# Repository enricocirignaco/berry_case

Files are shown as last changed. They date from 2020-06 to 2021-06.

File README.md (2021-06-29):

<!--
*** Thanks for checking out this README Template. If you have a suggestion that would
*** make this better, please fork the berry_case and create a pull request or simply open
*** an issue with the tag "enhancement".
*** Thanks again! Now go create something AMAZING! :D
***
***
***
*** To avoid retyping too much info. Do a search and replace for the following:
*** enricocirignaco(github_username), berry_case(repo), e.cirignaco@gmail.com(email)
-->

<!-- PROJECT LOGO -->
<br />
<p align="center">
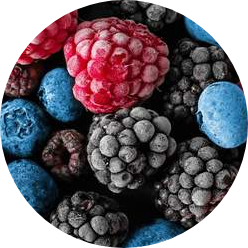
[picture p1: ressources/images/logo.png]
    
  </a>

  <h2 align="center">berry_case</h2>

  <p align="center">
    The open source Raspberry Pi case without compromises made by the community for the communnity
    <br />
    <br />
    <a href="https://github.com/enricocirignaco/berry_case/issues">Report Bug</a>
    ·
    <a href="https://github.com/enricocirignaco/berry_case/issues">Request Feature</a>
  </p>
</p>

<!-- TABLE OF CONTENTS -->
## Table of Contents

* [About the Project](#about-the-project)
  * [Starting Situation](#starting-situation)
  * [Aim](#aim)
  * [Product Requirements](#product-reqirements)
  * [Current Status](#current-status-(15.01.2021))
* [Hardware](#hardware)
  * [Schematics](#schematics)
    * [Main](#main)
    * [Power Supply](#power-supply)
* [Sofware](#software)
  * [Prerequisites](#prerequisites)
  * [Installation](#installation)
  * [Usage](#usage)
* [Mechannic](#mechanic)
* [Sources](#sources)
* [Contributing](#contributing)
* [License](#license)
* [Contact](#contact)

<!-- ABOUT THE PROJECT -->
# About The Project
An affordable and open source case for the Raspberry Pi 4 to help the users became more productive and portable then ever.

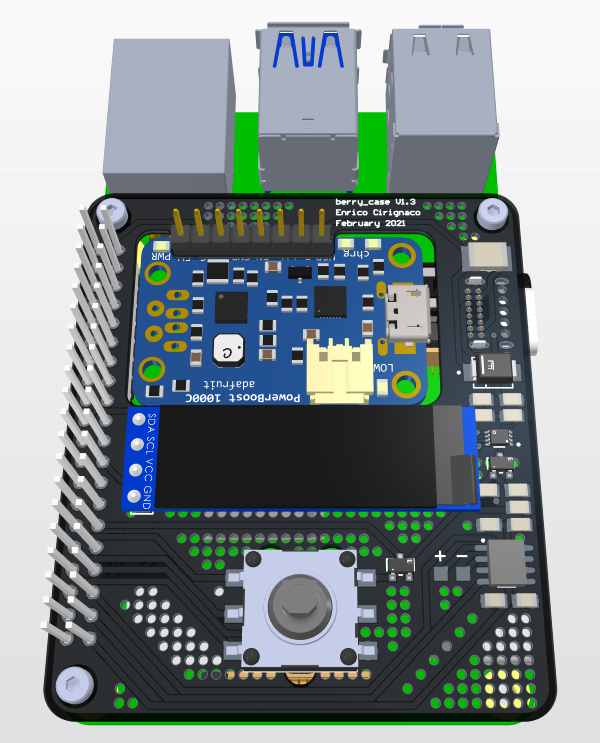
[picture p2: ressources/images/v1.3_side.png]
top_view


## Starting Situation

Surfing on the net I discovered some very cool case solutions for the RPi4. I almost ordered one of those products (Argon One). But then I realized that when the RPi4 was powered by a Power Bank(almost always in my case)(5V@2.1A) the CPU had some serious throttling problems. So overclocking with this power supply was out of discussion. I searched for an alternative battery powered power supply(5.2V@3A). Without success.
At the same time I discovered some interesting "Half-solutions":
* [Argon One](https://www.argon40.com/argon-one-raspberry-pi-4-case.html) (very nice design, power button, cooling system)
* [Acrylic Raspberry Pi set-top box kit](https://wiki.52pi.com/index.php/Acrylic_Raspberry_Pi_set-top_box_kit_SKU:_ZP-0098) (all IOs on the back, full dual HDMI)
* [Raspberry Pi RGB Cooling HAT](https://www.yahboom.net/study/RGB_Cooling_HAT) (OLED dipslay with IP address, CPU temp, etc)
* [Adafruit PowerBoost 1000 Charger](https://www.adafruit.com/product/2465) (UPS solution with Li-Ion cell, power supply)

So I decided to take inspiration from all this product and make my own solution! :)

## Aim
Develop and Build an affordable, open source, smart and good looking case for the Raspberry Pi 4.
Make good documentation and a building guide available to everyone so that anyone can build ther own case at home.
Find someone on github to collaborate with.

## Product Reqirements
* Size: max double the footprint of the RPi4. Max height not defined.
* Battery: min 2 hours of battery life.
* Cooling System: capable of cooling Overclocked RPi4.
* Power Button: capable of Soft and Hard Shutdown.
* PSU: UPS, BMS and 5.2V@min 2A output supply.
* Accessible GPIOs

## Current Status (15.01.2021)
Version 1.2 of the PCB is done. Software still in alpha phase. At the moment I'm focused on the Enclosure. I'm testing different 3D printed cases for the RPi4.

# Hardware
The PCB is developed with [Altium Designer](https://altium.com).
## Schematics
### Main
<a href="https://github.com/enricocirignaco/berry_case/blob/master/ressources/schematics/main.pdf">
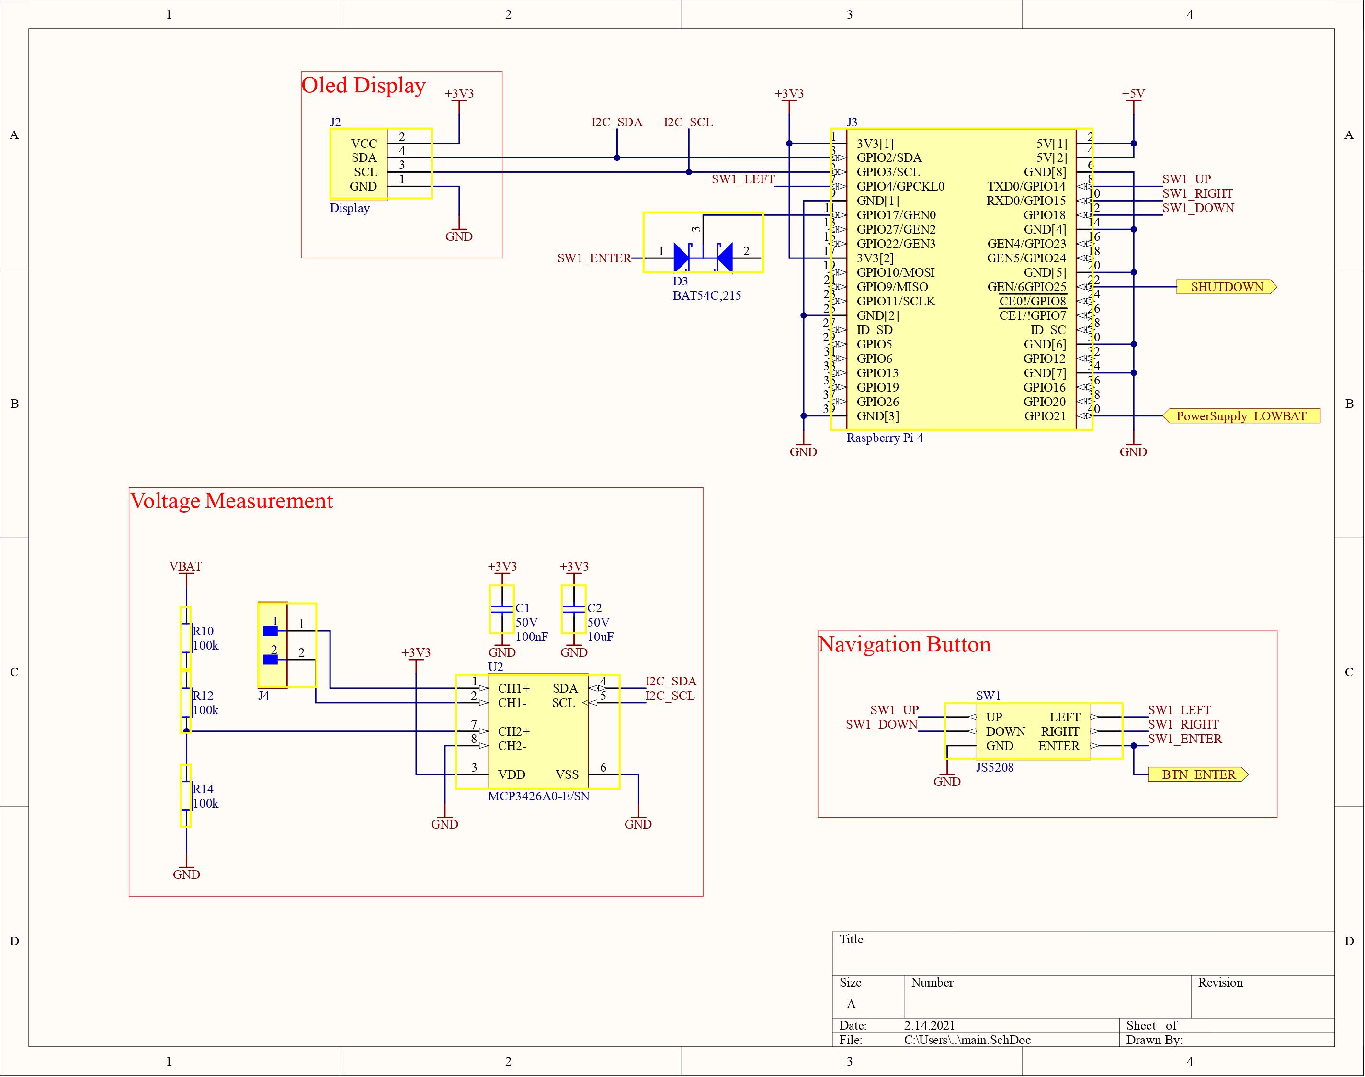
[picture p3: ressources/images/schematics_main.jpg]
  
</a>

### Power Supply
<a href="https://github.com/enricocirignaco/berry_case/blob/master/ressources/schematics/power_supply.pdf">
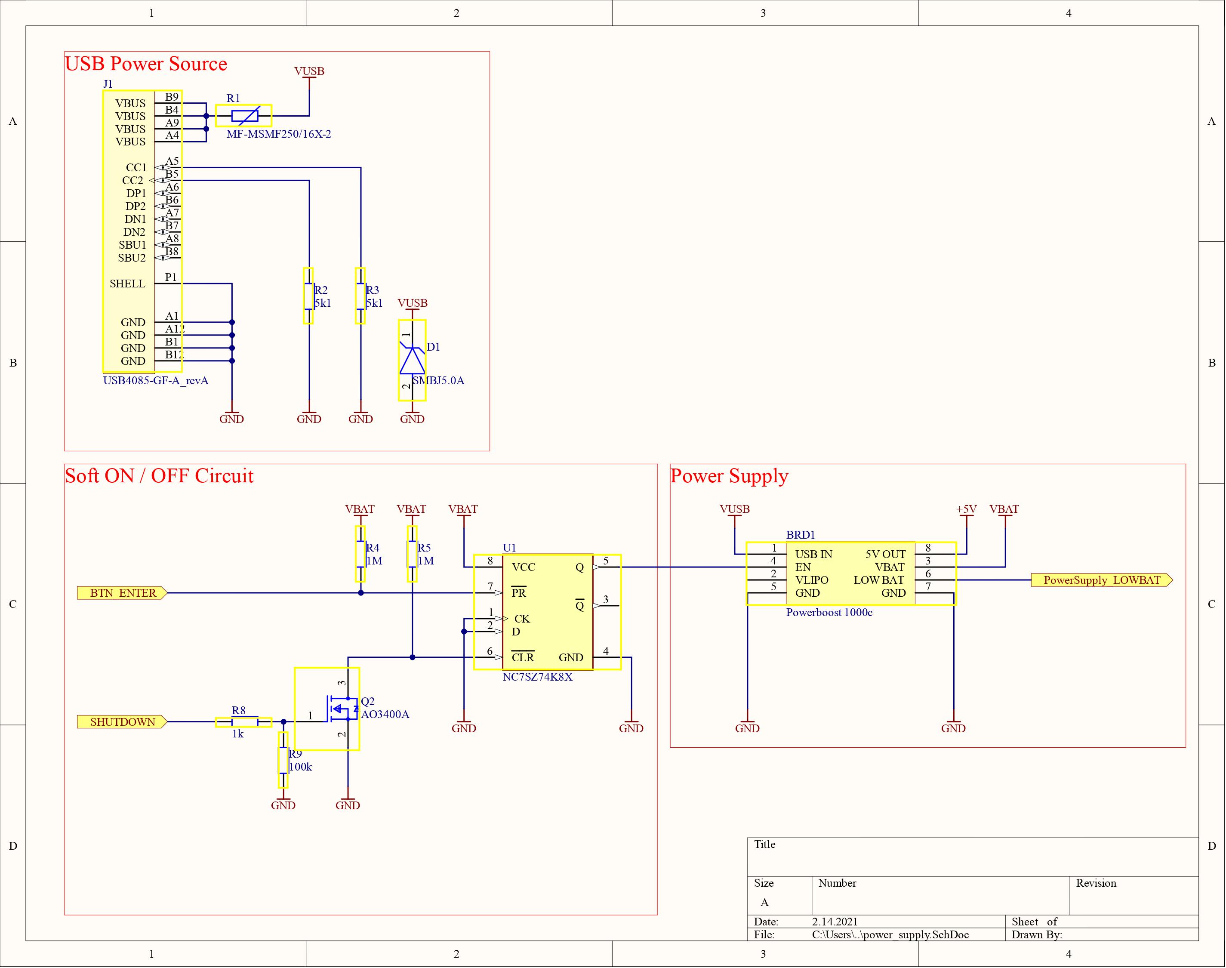
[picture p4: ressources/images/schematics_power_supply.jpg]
  
</a>

# Software
## Prerequisites
## Installation
## Usage
# Mechanic
The 3D Models are developed with [Autodesk Fuson 360](https://www.autodesk.com/products/fusion-360/overview)

# Sources
[datasheet oled display](https://www.mcielectronics.cl/website_MCI/static/documents/0.91inch_OLED_Module_User_Manual_EN.pdf)

[auto power off](http://crsengineering.altervista.org/eng/pi/pi_GPIO_poweroff_eng.html)

[networking tool](https://www.raspberryconnect.com/projects/65-raspberrypi-hotspot-accesspoints/183-raspberry-pi-automatic-hotspot-and-static-hotspot-installer)

# Contributing

I'm looking for someone that want to collaborate in this project. **Especially someone tha is good at 3D drawing.** I would like to get in touch with you if you are interested. :)

Contributions are what make the open source community such an amazing place to be learn, inspire, and create. Any contributions you make are greatly appreciated.

1. Fork the Project
2. Create your Feature Branch (`git checkout -b feature/AmazingFeature`)
3. Commit your Changes (`git commit -m 'Add some AmazingFeature'`)
4. Push to the Branch (`git push origin feature/AmazingFeature`)
5. Open a Pull Request

# License

# Contact

Enrico Cirignaco - e.cirignaco@gmail.com

Project Link: [https://github.com/enricocirignaco/berry_case](https://github.com/enricocirignaco/berry_case)

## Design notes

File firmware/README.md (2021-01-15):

# setup
## Install python libraries
* Run **install_oled.sh** script in the shell
* When installation script is done **raspi-config** window will open. 
    * Navigate to **Interface Options** and enter.
    * Navigate to **I2C** and confirm with yes.
    * Exit raspi-config
* Add user to GPIO, i2c and video group:
    * sudo adduser \<username> GPIO
    * sudo adduser \<username> i2c
    * sudo adduser \<username> video
* Reboot machine by typing **sudo reboot**

### add main.py script to programms to run at startup

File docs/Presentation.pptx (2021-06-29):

## Willkommen

## 37.000.000

Bis heute verkaufte Raspberry Pi

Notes: Allein in 2020 wurden 7 Milionen raspberry verkauft.
Ich selber besitze verschiedene modelle.
Ich entwickle fast täglich auf einem Raspberry

## Ziel dieses Projektes: Ein Zusatzmodul entwickeln um den Raspberry portabler zu machen

## Kritische Features

- Kommunikation mit dem Benutzer

Internetzugang

Akkubetrieb

Unterbruchsfreie Stromversorgung

## Zusäzliche Features

- Aktive und passive Kühlung des Prozessors

Benutzeroberfläche

Gehäuse für Raspberry & Zusaztmodul

ON/OFF Knopf

## Das Endprodukt:

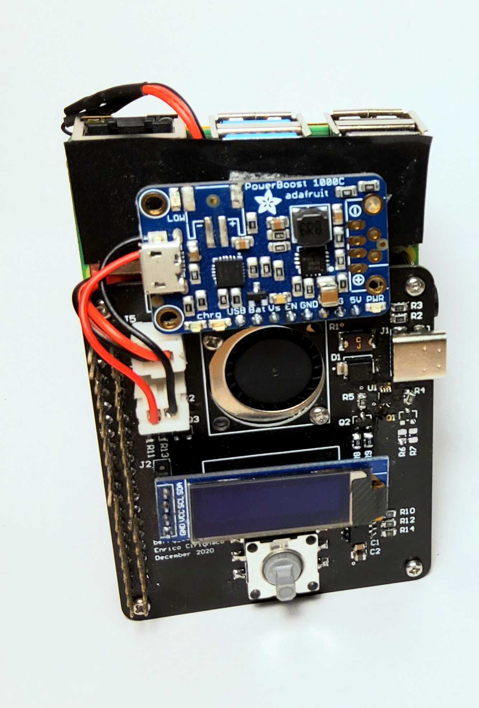
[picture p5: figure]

berrycase

## Netzwerk

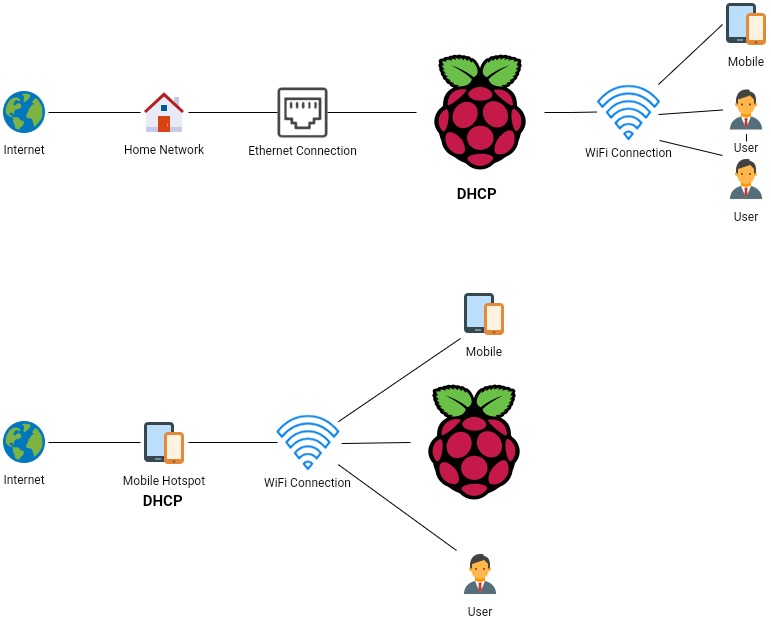
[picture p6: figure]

Access Point

Eigene Wi-Fi Netzwerk

## Speisung

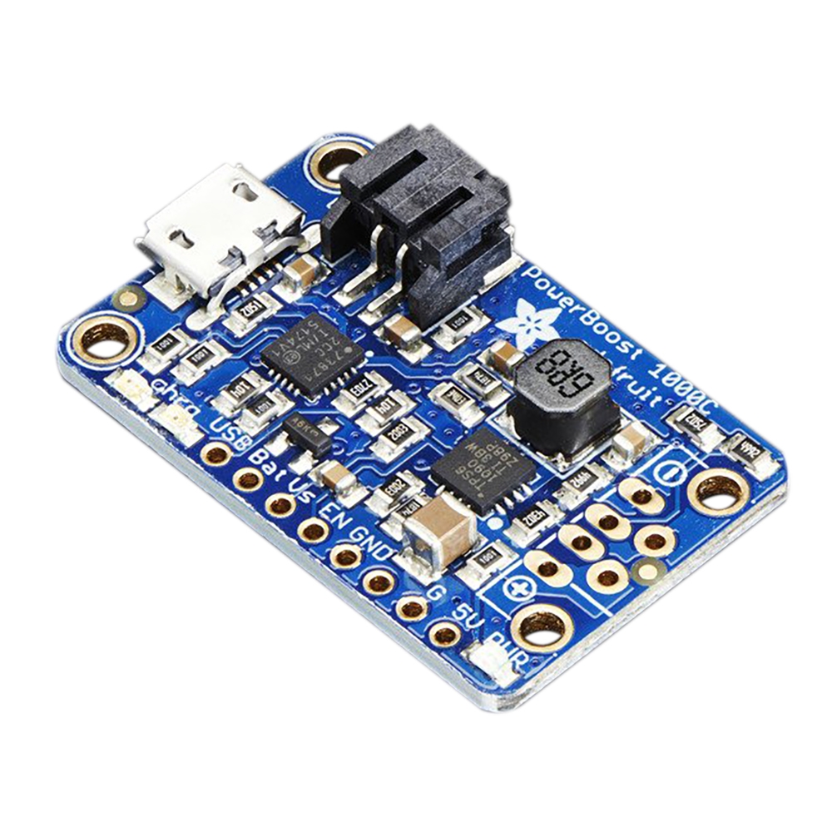
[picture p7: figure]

- MCP73871: Stand-Alone System Load Sharing and Li-Ion / Li-Polymer Battery Charge Management Controller
- TPS61090: Synchronous (96% Efficient) Boost Converter

## Benutzeroberfläche

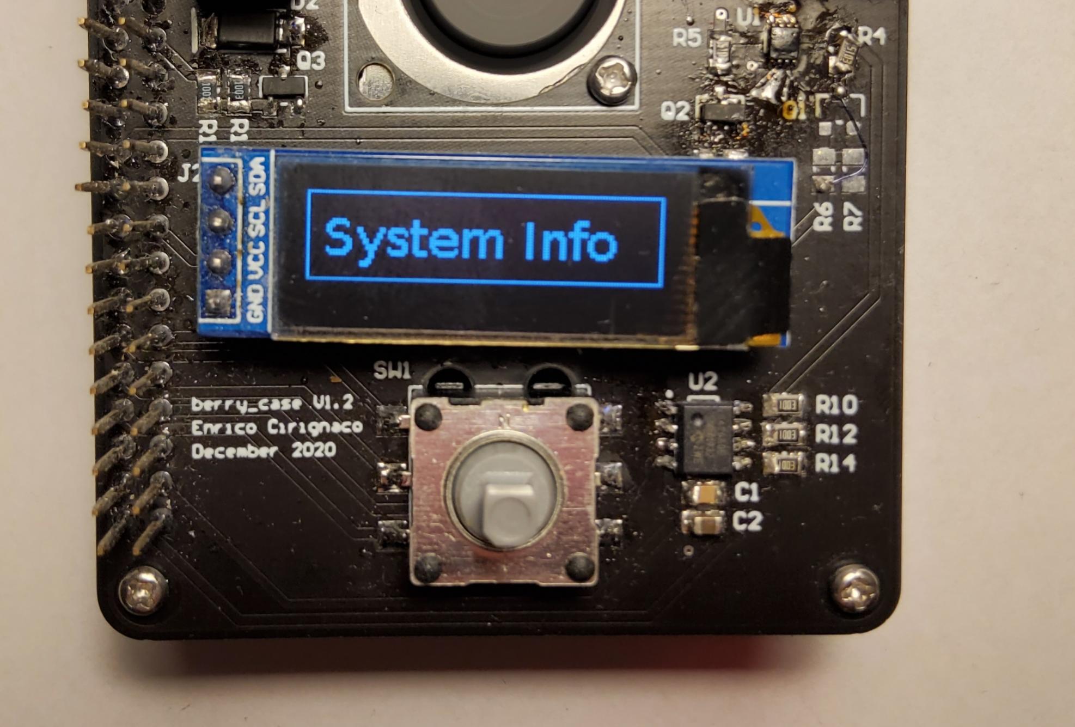
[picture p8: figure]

- 0.96 Zoll OLED Display
- Intuitiver Navigationstaster

## Kühlungsystem

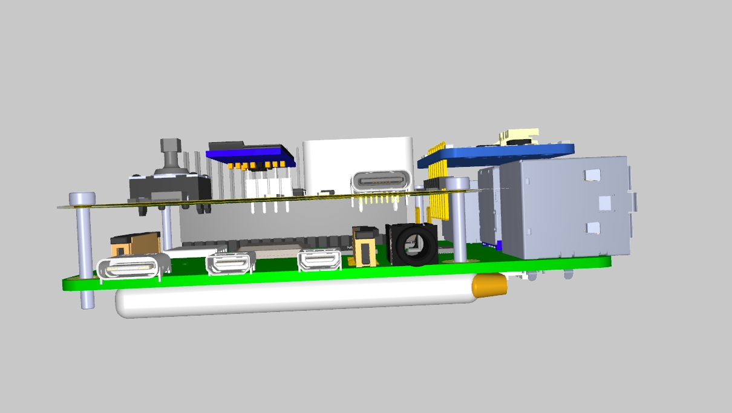
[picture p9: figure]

## Wie weiter?

- Komplettes Open-Source Projekt auf Github: enricocirignaco/berry_case
- Ein Gehäuse muss entwickelt werden
- Weitere Iterationen sind geplant
- Mithelfer gesucht

## Fragen oder Verbesserungsvorschläge?

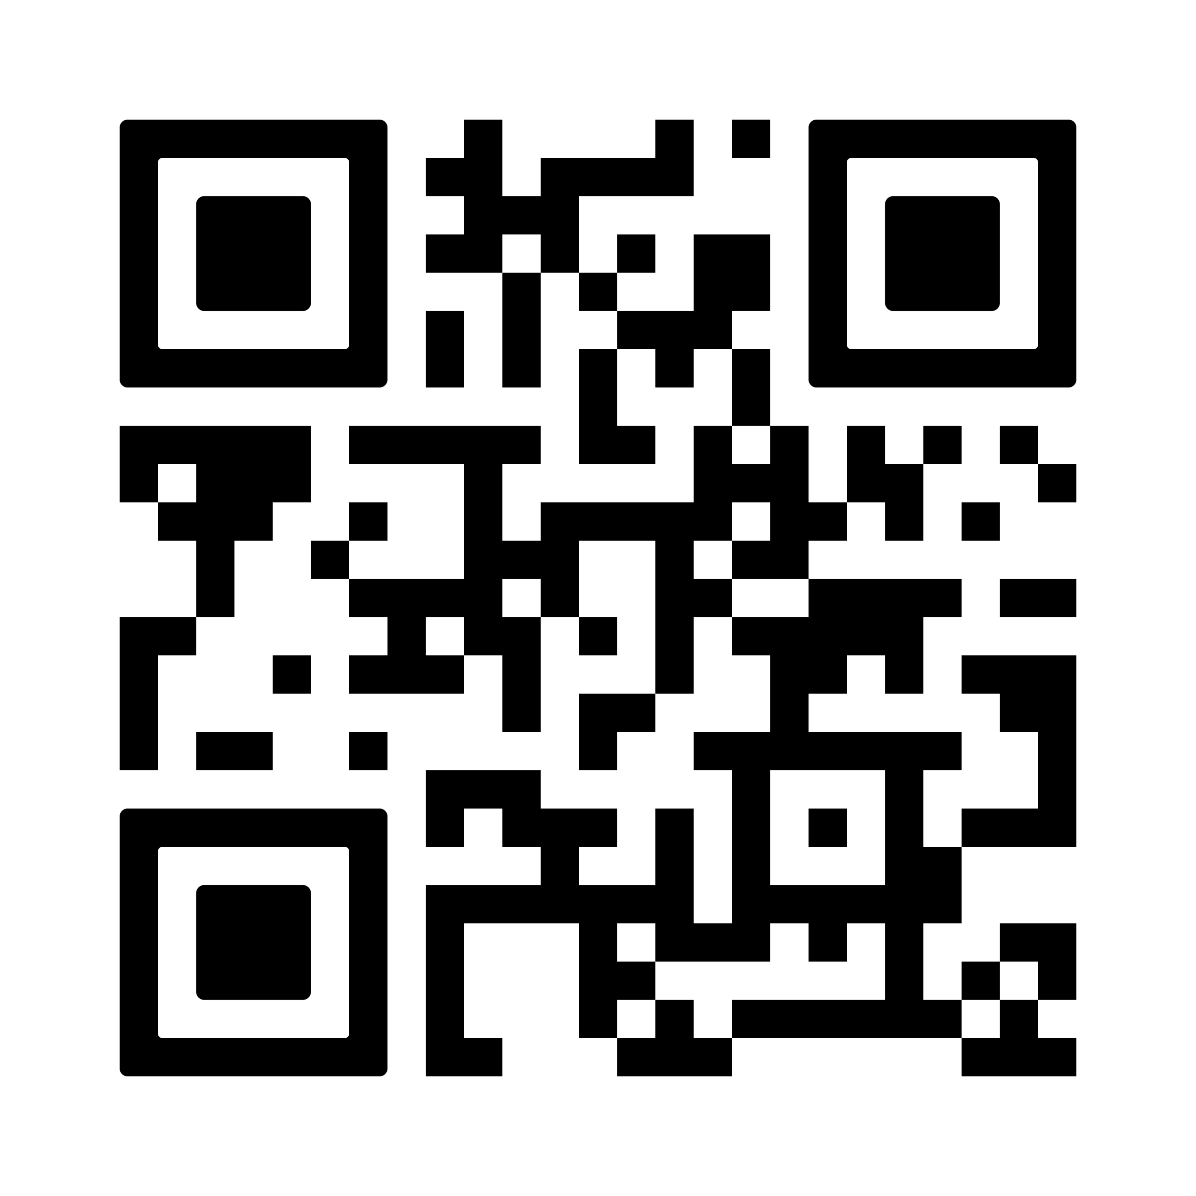
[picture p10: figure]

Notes: Falls jemand an das Projekt interesse hat kann diese QR code zu den github repository scannen.

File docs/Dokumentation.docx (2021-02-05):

Berrycase

# Berufsübergreifendes Projektarbeit

Eine Dokumentation über die Entwicklung ein multifunktionales Gehäuse für den Einplatinencomputer Raspberry Pi 4B.

Autor: Enrico Cirignaco
Fachvorgesetzte: Matthias Burri
Auftraggeber: Matthias Burri 05.02.21

# Abstract

Die im nachfolgenden Dokument beschriebene Arbeit wurde im Rahmen einer Berufsübergreifenden Projektarbeit (BüP) durchgeführt:

Die Aufgabe lautete, ein Gerät zu entwickeln das ermöglicht, unterwegs mit dem Raspberry zu arbeiten und die allgemeine Produktivität der Benutzer zu steigern. Daher muss eine ansteckbarer Leiterplatte und ein Gehäuse entwickelt werden. Im Gehäuse muss einen Akku integriert werden, so dass das Gerät auch ohne Netzspeisung benutzt werden kann.

Als Vorarbeit zu dieser Aufgabe wurde eine kleine Marktanalyse gemacht, um zu wissen ob ähnliche Lösungen auf dem Markt schon vorhanden sind. Dazu wurde auch die technische Machbarkeit untersucht.

Das Gehäuse ist mit einem OLED Display und ein Navigationsknopf ausgestattet. Damit können Einstellungen gemacht werden und Systeminformationen eingeblendet werden. Um den Rechner kühl zu behalten wurde im Gerät ein 20mm Lüfter eingebaut. Die Geschwindigkeit des Lüfters kann mit einem automatischen oder einem manuellen Modus angesteuert werden. Die Kerneigenschaft vom berrycase ist die UPS Funktion (aus dem Englischen Unterbrechungsfreie Stromversorgung). Dies ermöglich vom Akkubetrieb auf Netzbetrieb (und umgekehrt) zu wechseln, ohne das System herunterfahren zu müssen.

Am Ende der Arbeit wurden alle grundlegenden Ziele erreicht und es konnte sogar begonnen werden, am optionalen Ziel zu arbeiten. Dieses wurde aber nicht abgeschlossen. Verbesserungen, die noch implementiert werden könnten, wären das 3D Gehäuse fertig zu entwickeln und auszudrucken. Zudem könnte ein grösserer Akku eingebaut werden. Das Kühlungssystem könnte auch so erweitert werden, dass die CPU/GPU übertaktet werden kann.

Inhaltsverzeichnis

# Abbildungsverzeichnis

# Abkürzungsverzeichnis

OLED Organic Light Emitting Diode

UPS Uninterruptible Power Supply

CPU Central Processing Unit

GPU Graphics Processing Unit

UX User Experience

IP Internet Protocol

GPIO General-purpose input/output

BüP Berufsübergreifendes Projekt

BMS Battery management system

AP Access Point

I2C Inter-Integrated Circuit

PCB Printed Circuit Board

PWM Pulse-Width Modulation

RS-Flip-Flop Reset Set Flip Flop

D-Flip-Flop Data Flip Flop

MOSFET Metal Oxide Semiconductor Field Effect Transistor

kV Kilovolts

BVDSS Drain-Source Breakdown Voltage

VDS Drain-Source Voltage

SoC System on a chip

PIR Passive Infrared Sensor

TVS Transient-voltage-suppression diode

PTC Positive Temperature Coefficient
ADC Analog-Digital-Converter
I/O Inputs/Outputs
LED Light Emitting Diode
uC Mikrocontroller
GND Ground
V Volt
A Ampere
IC Integrated Circuit

# 1 Einleitung

Im Rahmen einer Vorbereitung für die zukünftige Individuelle Projektarbeit soll dieses Projekt durchgeführt werden.

## 1.1 Aufgabenstellung

Den Raspberry Pi unterwegs zu benutzen ist sehr umständlich. Eine Powerbank ist nötig und ein Netzwerk muss aufgesetzt werden. Um die UX (Nutzererfahrung) zu steigern, muss ein Gehäuse für den Einplatinencomputer entwickelt und gebaut werden.

Das Gehäuse muss klein gehalten werden. Eine UPS Funktion muss implementiert werden. Man muss Minimum zwei Stunden im Akkubetrieb arbeiten können. Das Gehäuse muss mit einem Kühlungssystem für die CPU und einem kleinen Display, um die IP-Adresse anzuzeigen ausgestattet werden. Die GPIOs von Raspberry müssen zugänglich bleiben.

## 1.2 Vorgehen

Während der Dauer der BüP soll das Konzept erarbeitet werden, die Elektronik entwickelt und gefertigt werden.

Zusätzlich muss die Software geschrieben werden. Folgende Arbeiten gehören zur BüP:

• Grobplanung

• Vorstudie

• Konzept erarbeiten

• Hardware Entwicklung

• Firmware / Software Entwicklung

• Testing / Bugfixing

• Dokumentation

Das Projekt wird mit der „Agilen Arbeitsmethodik“ geleitet. Dementsprechend wird in der Startphase nur eine Grobplanung gemacht und die Meilensteine werden festgesetzt. Ein SCRUM Board und das Project Management Tool „Trello“ werden eingesetzt.

Das Projekt wird mit GIT verwaltet und auf Github dokumentiert. Alle Projektunterlagen sind Open-Source. Das Arbeitsjournal wird elektronisch geführt.

## 1.3 Zielsetzung

Das Projekt wurde in zwei Zielbereiche unterteilt. In einen grundlegenden und in einen optionalen Zielbereich.

### Grundfunktionen

- Batteriebetrieb (Minimum zwei Stunden Autonomie)
- Aktives Kühlungssystem
- Einschaltknopf
- Ausschaltknopf (mit soft Shutdown)
- Unterbrechungsfreie Stromversorgung (UPS)
- Batteriemanagementsystem (BMS)
- Die GPIOs vom Raspberry müssen zugänglich bleiben
- Das Gehäuse darf maximal doppelt so gross wie der Raspberry sein
- Display, um Informationen anzuzeigen
- Stromversorgung über USB Type-C

### Optional

Die optionalen Ziele sollen erst realisiert werden, sobald die Grundfunktionen alle einwandfrei funktionieren. Optional soll mithilfe eines CAD Tools ein passendes Kunststoff Gehäuse gezeichnet und mit einem 3D Drucker ausgedruckt werden.

# 2 Hardware

## 2.1 Konzept

In diesem Abschnitt sollen die einzelnen Schaltungsteile analysiert und evaluiert werden. Hierbei ist darauf zu achten, dass einige Teile der Schaltung von vorhergegangenen und Open Source Projekten übernommen wurden und daher nicht überall neue Evaluationen durchgeführt wurden.

### Mikrokontroller

Die Funktion der Mikrokontroller übernimmt in diesem Fall der Raspberry Pi selber. Der Mikrokontroller dient in dieser Anwendung zur Ansteuerung der einzelnen Hardwarekomponenten und als Router für das aufgesetzte Netzwerk.

#### 2.1.1.1 Vorgaben

Der Kontroller muss folgende Punkte erfüllen:

- Auf dem Kontroller muss ein Wi-Fi AP (Access Point) aufgesetzt werden können
- PWM zu Ansteuerung der Lüfter
- I2C zu Ansteuerung des Displays und der ADC
- Es werden insgesamt 7 I/Os (Inputs/Outputs) benötigt, um die Hardwareteile anzusteuern.

### OLED Display

Um nutzvolle Informationen anzuzeigen wurde entschieden, ein OLED Display einzusetzen. Die Hauptvorteile diese Technologie sind, dass keine Hintergrundbeleuchtung benötigt wird und seine hervorragender Kontrasteigenschaft. Dazu sind diese Displays preisgünstig und stromsparender. Das ausgewählte OLED Display hat eine Bilddiagonale von 0.91 Zoll und eine Auflösung von 128x32 Pixels. Die Anzeige kann mit 3.3v und 5v gespeist werden. Angesteuert wird sie über das I2C Protokoll.

Abbildung 1: OLED Display

### UPS & BMS

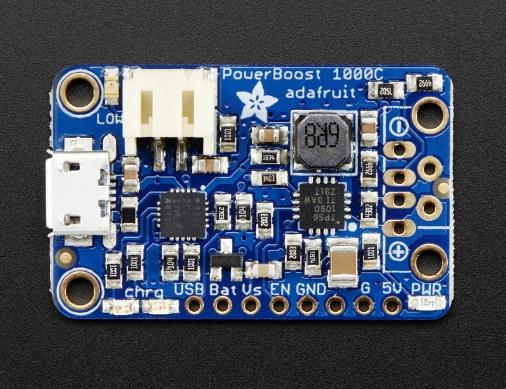
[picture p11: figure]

Auf dem Markt gibt es schon eine Lösung, die genau die in diesem Projekt benötigten Funktionalitäten aufweist. Der PowerBoost 1000c des Herstellers Adafruit. Die Entwicklungsunterlagen dieses Produkts sind frei zugänglich und Open-Source. Es wurde zuerst evaluiert ob es sinnvoll wäre, die Schaltung auf eine eigene Leiterplatte zu integrieren oder das Produkt von Adafruit zu übernehmen. Zwei kritische Bauteile der Schaltung können nur mit speziellen Werkzeugen bestückt werden. Dazu ist der Preisunterschied zwischen den zwei Varianten nicht sehr gross. Es wurde darum entschieden die fertige Leiterplatten von Adafruit einzukaufen und im Projekt zu integrieren.

Abbildung 2: PowerBoost 1000C

### Soft-Power OFF

Der Raspberry muss mithilfe der Benutzeroberfläche ausgeschaltet werden können. Nachdem der Raspberry heruntergefahren wird, verbraucht das System weiter Energie. Als Folge wäre die Batterie innerhalb ein paar Stunden komplett leer. Um dieses Problem zu umgehen, muss die Speisung ausgeschaltet werden. Das kann mit der Ansteuerung der «Enable» Pin der PowerBoost 1000c Board realisiert werden.

### Batterie-Spannungsmessung

Die Spannung kann einfach mit einem Spannungsteiler umgewandelt werden und mit einem ADC ausgewertet werden. Da der Raspberry Pi nicht mit einem ADC ausgestattet ist, muss ein Externes evaluiert werden. Für die Kommunikation zwischen ADC und uC soll das Protokoll I2C angewendet werden. Der MCP3426 vom Hersteller Microchip wurde ausgewählt.

Der gewählte AD-Wandler besitzt folgende Eigenschaften:

- 16bit Auflösung
- 2 Differenzeingänge
- Delta-sigma verfahren
- I2C Schnittstelle

## 2.2 Realisierung

In diesem Abschnitt wird auf die Realisierung der Hardware genauer eingegangen und die einzelnen Schaltungsblöcke werden genauer erklärt.

### Blockschaltbild

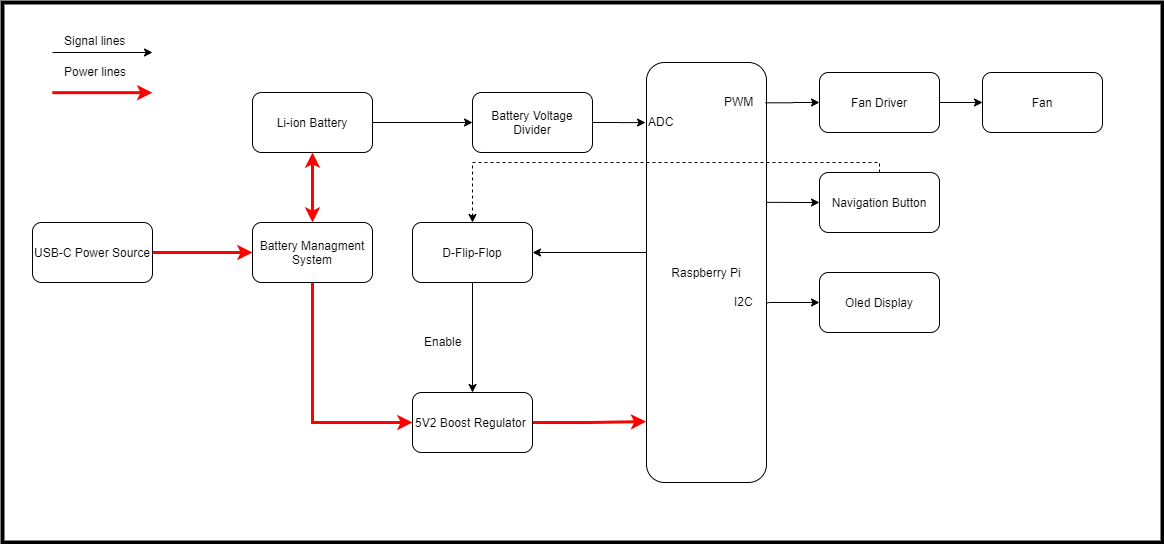
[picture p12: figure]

Abbildung 3: Blockschaltbild

### Mikrokontroller

Der Mikrocontroller ist der Kern der Hardware und steuert alle anderen Baugruppen. Integriert auf dem Board ist auch die 3.3V Speisung.

### Speisung

Das Gerät wird über USB gespeist, somit ist die Speisung schon vorhanden. Was noch implementiert worden ist, ist eine Schutzschaltung, um das Gerät gegen Überspannungen und Überlastungen zu schützen. Die Schaltung wurde von einem vorherigen Projekt übernommen. Die TVS Diode D1 dient als Schutz gegen Überspannungen. Der Widerstand R1 ist eine PTC rücksetzbare Sicherung, die bei einem Strom von 2.5A oder höher ihr interner Widerstand erhöht und konsequent die Schaltung trennt.

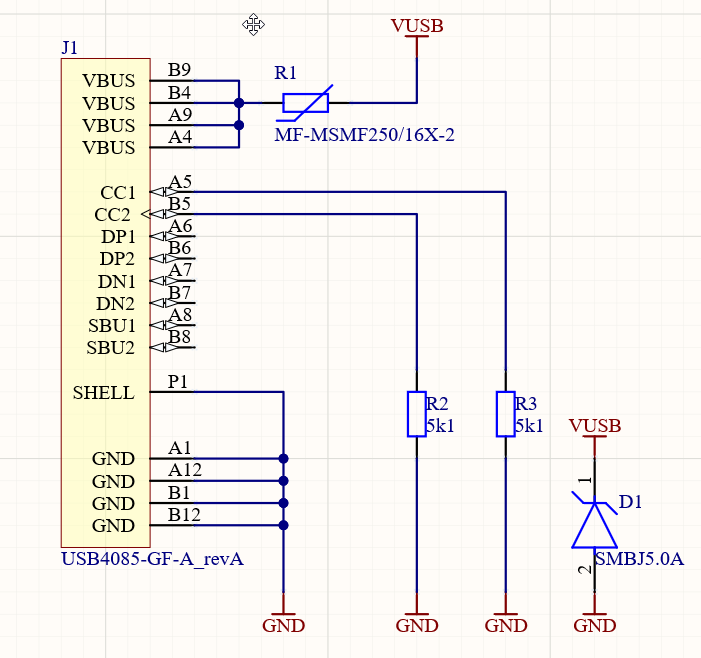
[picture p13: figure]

Abbildung 4: USB Type-C und Schutzschaltung

Wie im Dokument «Introduction to USB Type-C™» von Microchip empfohlen wird, wurden zwei 5k1 Widerstände zwischen Ground und Pin CC1 und CC2 von der USB Buchse bestückt. Diese stellen sicher, dass das Gerät mit genügend Leistung von der USB-Speisung versorgt wird.

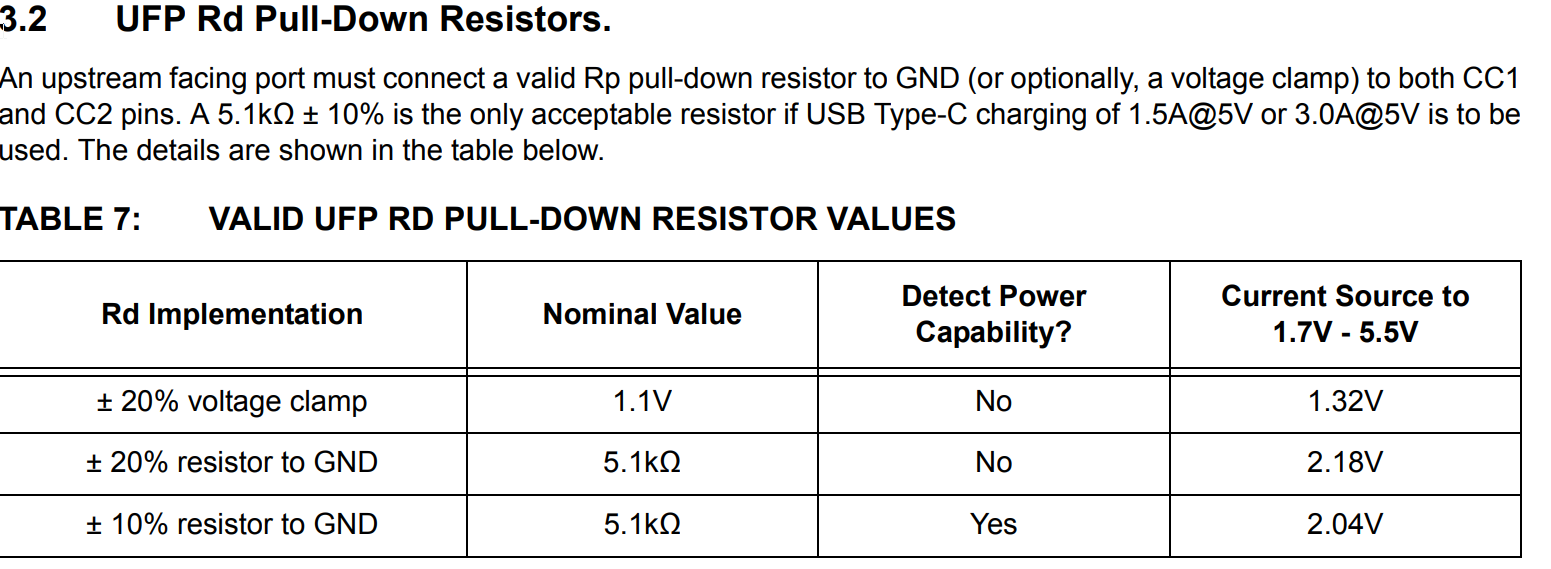
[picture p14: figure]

Abbildung 5: Ausschnitt aus dem PDF «Introduction to USB Type-C™»

Teil der Speisung ist auch das externe Board PowerBoost 1000c. Die externe Speisung, die Batterie und der 5V Ausgang müssen an diese Schaltung angeschlossen werden. Zusätzlich sind eine Leitung für den Enable Pin und eine Leitung für den Batteriezustandmelder mit dem Board verbunden.

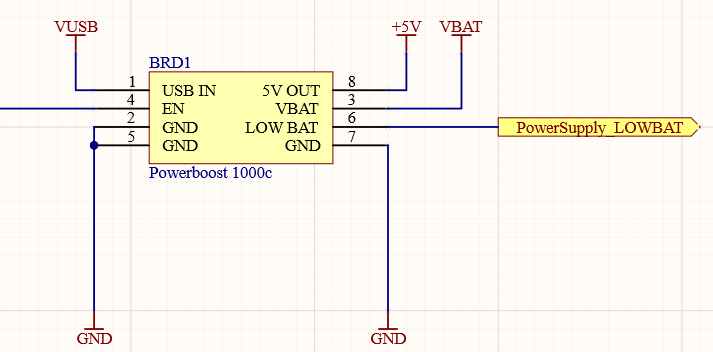
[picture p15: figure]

Abbildung 6: PowerBost 1000c

### Batterie Spannung Messung

Die Messung der Spannung erfolgt über den Spannungsteiler (R10-R12-R14). Da die drei Widerstände genau den gleichen Wert haben (±1%), entspricht die Ausgangspannung einem Drittel der Eingangsspannung. Dieser Pegel wird dann mit dem ADC ausgewertet. Der ADC arbeitet mit einer internen Spannungsreferenz von 2,048V. Die maximale Spannung an den Differenzeingängen darf diesen Wert nicht überschreiten. C1 und C2 schützen den ADC gegen Störungen.

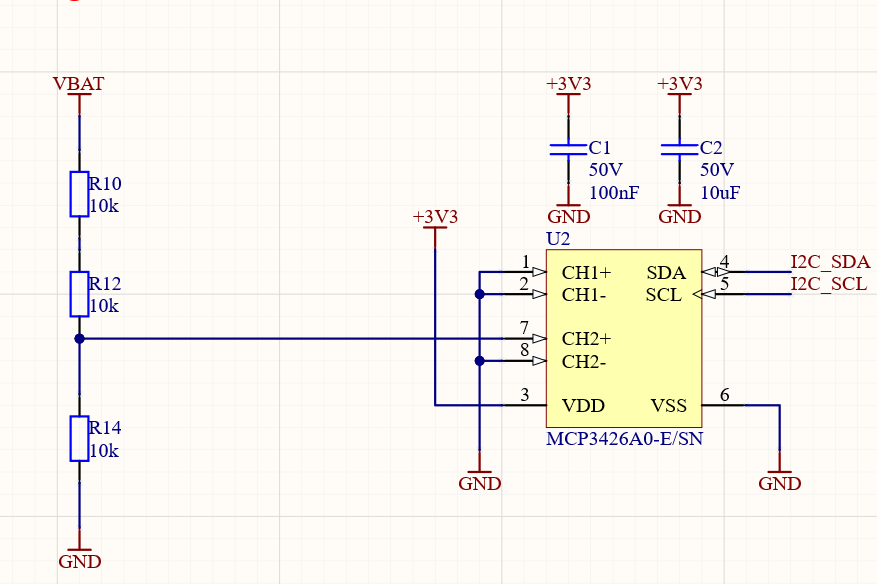
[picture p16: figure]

Abbildung 7: Spannungsmessung

### Soft Power ON/OFF Schaltung

Der Schaltregler auf dem PowerBoost Board kann mit der Ansteuerung der Enable Pin ein- und ausgeschaltet werden. So kann die Speisung den Raspberry Pi komplett trennen.

Abbildung 8: : Ausschnitt aus dem Datenblatt vom TPS61090

Um den Enable Pin immer in einem definierten Zustand ohne externe Handlung zu behalten, wird er mit einem RS-Flip-Flop angesteuert. Dieser Flip-Flop Typ ändert seinen Ausgangszustand nur, wenn eine Flanke auf dem Set oder Reset Pin detektiert wird. Das ausgewählte Flip-Flop ist der NC7SZ74K8X des Herstellers ON Semiconductor. Dieses Model kann entweder als D- oder RS-Flip-Flop verwendet werden. Für diese Anwendung wird ein RS Typ benötigt. Anhand der unterstehenden Wahrheitstabelle kann man sagen, dass wenn eine negative Flanke auf dem Clear Pin ist, wird die Speisung ausgeschaltet und wenn eine negative Flanke auf dem Preset Pin ist, wird die Speisung eingeschaltet.

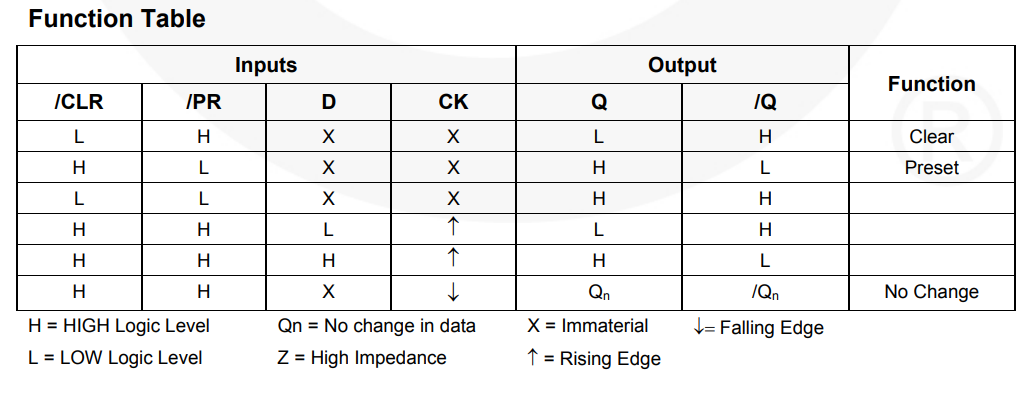
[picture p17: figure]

Abbildung 9: Ausschnitt aus dem Datenblatt vom NC7SZ74K8X

Da der Logikpegel des Raspberry niedriger als die Spannung der Batterie ist, wird ein Pegelwandler benötigt. Dieser wurde mit zwei MOSFET (Q1 und Q2) realisiert.

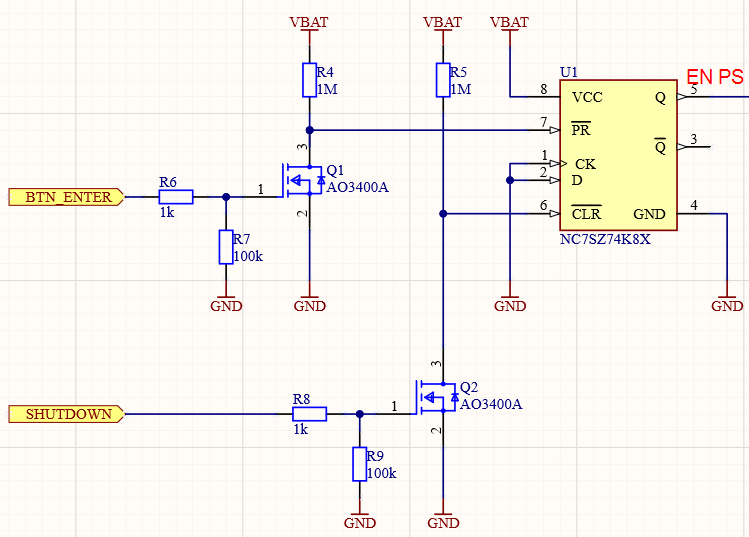
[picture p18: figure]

Abbildung 10: Soft ON/OFF Schaltung

### Lüfter Steuerung

Der Lüfter wird mit einem PWM Signal angesteuert. So kann die Geschwindigkeit des Lüfters fein eingestellt werden. Da ein GPIO vom Raspberry nicht die benötigte Leistung erbringen kann, wird die Leistung mit einem MOSFET angesteuert. Der Motor des Lüfters ist eine induktive Last. Folglich, wenn die Schaltung geöffnet wird und kein elektrischer Strom mehr fliesst, bricht das magnetische Feld in den Wicklungen des Motors zusammen und eine elektrische Spannung wird induziert. Diese Spannung kann bis zu einigen kV (Kilovolts) gross werden. Die MOSFET sind allgemein auf grosse Spannungen sehr empfindlich. Die in diesem Projekt angewendete AO3400A hat eine BVDSS (Drain-Source Breakdown Voltage) von nur 30V. Ohne ein Überspannungsschutz würde der MOSFET nach einigen Schaltvorgängen kaputt gehen. Um dieses Problem zu umgehen wurde die Freilaufdiode D2 eingebaut. Damit wird sichergestellt, dass die VDS Spannung (Drain-Source Voltage) von Q3 nie grösser als 5.7V wird.

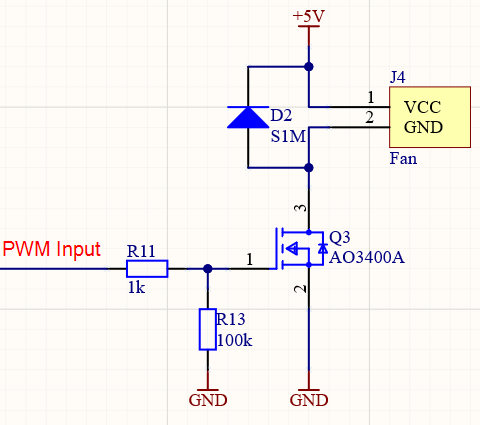
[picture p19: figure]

Abbildung 11: Lüfter Steuerung Schaltung

### Bedienung Komponenten

Die Bedienung des Geräts erfolgt über ein OLED Display und einen 5-fachen Navigationsknopf. Das Display wird über I2C angesteuert und mit 3.3V gespiesen. Die Pull-up Widerstände für die I2C sind auf dem Raspberry schon vorhanden. Der Navigationsbutton ist direkt mit 5 GPIOs der Raspberry Pi verbunden. Pull-up Widerstände werden dann Softwaremässig eingeschaltet. Die Entprellung wird auch Softwaremässig implementiert.

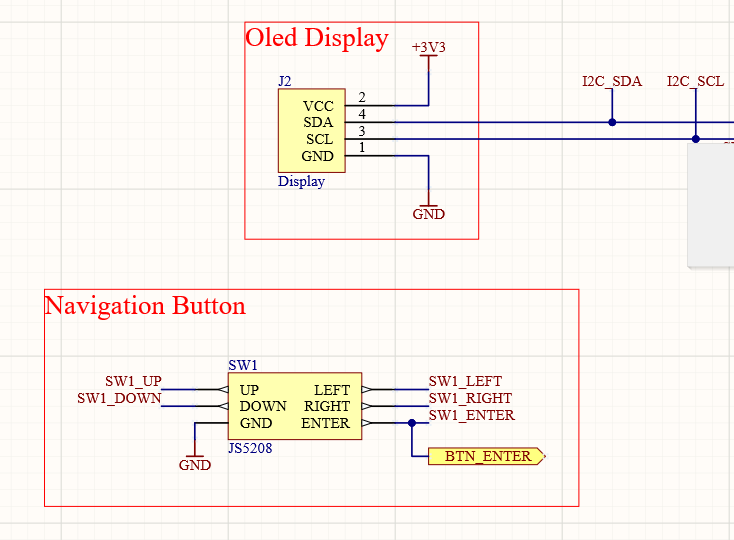
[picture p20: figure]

Abbildung 12: Bedienung Komponenten Schaltung

# 3 Software

In diesem Abschnitt der Dokumentation sollen die einzelnen Teile der Software analysiert und erklärt werden. Die Software besteht aus einem Hauptprogramm und verschiedenen kleineren unabhängigen Skripts.

## 3.1 Hauptprogramm

Die Software für die Steuerung der Hardware wurde in Form von Python Skripts geschrieben. Das Hauptprogramm ist zuständig für die Interaktion mit dem Benutzer.

### Aufbau

Die Software wurde modular strukturiert. Das bedeutet, dass jede Peripherie in ein eigenes Modul aufgeteilt ist und alle Funktionen, welche für die Ansteuerung der jeweiligen Peripherie benötigt werden, darin enthalten sind. Diese Files können im Hauptprogramm als Python Module eingebunden werden. Lediglich alle Variablen und Parameter wurden in den entsprechenden Modulen zusammengefasst.

### Ablauf Flussdiagramm

Der Softwareablauf entspricht grundsätzlich dem Modell eines Flussdiagramms. Dies liegt daran, dass solange keine Taster gedrückt werden, das Programm immer denselben Ablauf durchführt. Erst sobald eine Callback von der GPIOs ausgelöst wird, wird gehandelt. Aus diesem Grund wird die Software mit Hilfe des Flussdiagramms in Abbildung 10 dargestellt.

Wenn das Programm gestartet wird, wird automatisch der erste Eintrag des Hauptmenus auf dem Display dargestellt. Mit den Tasten Hoch und Runter kann man zwischen den verschiedenen Einträgen navigieren. Um in ein Untermenü zu gehen muss der Knopf in der Mitte gedrückt werden. Analog zu Hauptmenü können die Untermenüs mit den Tasten Hoch und Runter gesteuert werden. Um zurück in das Hauptmenü zu gelangen muss die Taste in der Mitte gedrückt werden.

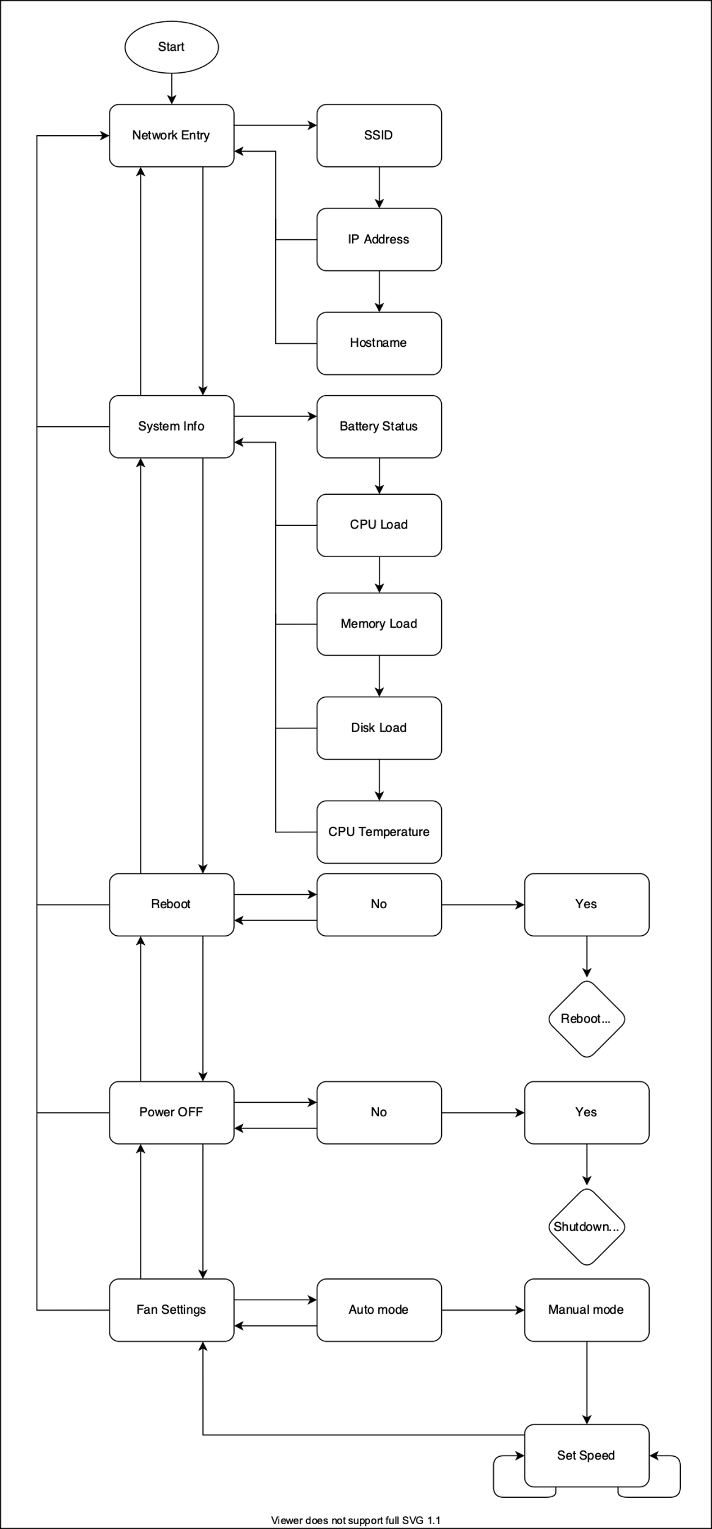
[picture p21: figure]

Abbildung 13: Flussdiagramm Hauptprogramm

### Konfiguration

Damit der Python Script fehlerfrei funktionieren kann, müssen die benötigten Python Libraries installiert werden. Zusätzlich muss die Hardware einmalig konfiguriert werden. Um diese Aufgaben zu erledigen wurde ein Shell Skript geschrieben. Beim Ausführen wird zuerst das Betriebssystem auf den neusten Stand aktualisiert. Danach werden die benötigten Programme, falls nicht vorhanden, installiert. Gleichzeitig wird Python3 als Standard Python Interpreter eingestellt. Danach werden die Python Libraries installiert, um die GPIOs und das Display ansteuern zu können. Schliesslich wird der I2C Bus aktiviert und die I2C Clock vom Standardwert von 100kHz auf 1Mhz eingestellt.

### System Befehle

Um auf Systeminformationen zuzugreifen wurden Bash Befehle benutzt. Bash ist die Standard Linux Shell. Mithilfe einer Funktion des «subprocess» Standardmodul können innerhalb ein Python Script Bash Befehle ausgeführt werden. Das Resultat wird dann in Variablen gespeichert.

#### 3.1.1.1 SSID

iwgetid -r

Mit diesem Befehl kann der Name des Wi-Fi Netzwerks, mit dem das Gerät momentan verbunden ist, ausgeben.

#### 3.1.1.2 IP-Adresse

hostname -I | cut -d' ' -f1

Mit diesem Befehl kann die IP-Adresse ausgegeben werden. Mithilfe des «cut» Befehls wird die Ausgabe formatiert.

#### 3.1.1.3 CPU-Auslastung

top -bn1 | grep load | awk '{printf \"%.2f%%\", $(NF-2)}'

Mit diesem Befehl wird die CPU-Auslastung in Prozent ausgegeben. Mit dem Befehl «awk» wird den Wert mit zwei Nachkommastellen formatiert und danach das Prozentzeichen «%» angehängt.

#### 3.1.1.4 CPU-Temperatur

cat /sys/class/thermal/thermal_zone0/temp | awk '{printf \"%.2f\", $1/1000}'

Mit diesem Befehl wird die CPU-Temperatur in Milligrad Celsius ausgegeben. Mithilfe des «awk» Befehls wird den Wert in Grad Celsius umgerechnet und mit zwei nachkommastellen ausgegeben.

#### 3.1.1.5 RAM-Auslastung

free -m | awk 'NR==2{printf \"%.2f%%\", $3*100/$2 }'

Mit diesem Befehlt werden die frei verfügbare Programspeicher und die gesamten physisch installierten Speicher ausgegeben. Beide Werten in Megabytes. Mit dem «awk» Befehl wird die frei verfügbarer RAM in Prozent ausgerechnet und mit zwei relevanten Nachkommastellen ausgegeben.

#### 3.1.1.6 Flash Speicher Auslastung

df -h | awk \'$NF=="/"{printf "%d/%dGB %s", $3,$2,$5}\'

Mit diesem Befehl werden die gesamten physisch installierten Speicher in Gigabytes und der frei verfügbare Speicher in Gigabytes und in Prozent ausgegeben. Mit dem Befehl «awk» werden die Werte formatiert ausgegeben.

## 3.2 Auto Startup

Das Hauptprogramm muss nach jedem Neustart automatisch gestartet werden. Zudem muss das Skript in Hintergrund laufen. Es hat verschieden Möglichkeiten, diesen Vorgang zu automatisieren. Es wurde entschieden, das Tool Cron einzusetzen.

### Crontab

Aus dem Wikipedia Artikel über Cron:

«Der Cron-Daemon dient der zeitbasierten Ausführung von Prozessen in Unix und unixartigen Betriebssystemen wie Linux, BSD oder macOS, um wiederkehrende Aufgaben – Cronjobs – zu automatisieren.»

Grundsätzlich können Aufgaben in ein sogenannten Crontab File hinzugefügt werden, dazu muss spezifiziert werden, wann die Aufgaben ausgeführt werden müssen (Zeit oder Ereignisse wie z.B. Neustart). Jeder Benutzer hat ein Cron File.

Um dieses File zu öffnen muss folgendes Kommando ausgeführt werden:

crontab -e

In diesem Fall sieht der Eintrag für diese Aufgabe so aus:

@reboot /home/dev/documents/berry_case/firmware/python/autostart.sh

In anderen Worten, nach jedem Neustart führt das Skript «autostart.sh» aus.

### Autostart Skript

Das Skript sieht so aus:

# Project: berry_case

# File: autostart.sh

# Autor: Enrico Cirignaco

# Created: 11.12.2020

# Description: This script need to be added to the crontab of the pi user.

# crontab -e --> @reboot /home/dev/documents/berry_case/firmware/python/autostart.sh

# This script just run the main Python script wit sudo rights in background.

#!/bin/bash

cd /home/dev/documents/berry_case/firmware/python/

sudo -E python3 ./main.py &

Bevor das Hauptprogramm ausgeführt werden kann muss sichergestellt werden, dass man sich im richtigen Directory befindet. Das geschieht mit dem «cd» Kommando. Danach wird das Hauptprogramm mit Python, als Administrator im Hintergrund ausgeführt.

## 3.3 Netzwerk

Das Netzwerk von Raspberry muss so aufgesetzt werden, dass beim Neustart nach einem bekannten Wlan-Netzwerk gesucht wird. Wenn eins gefunden wird, wird eine Verbindung hergestellt. Wenn kein bekanntes Netzwerk gefunden wurde, wird auf dem Raspberry ein Access Point eingerichtet.

Somit kann sich der Benutzer in jeder Situation mit dem Raspberry verbinden.

Auf dem Internet wurde ein Tool gefunden, mit dem das gewünschte Netzwerk eingerichtet werden kann. Dieses Tool wurde netterweise vom Besitzer der Webseite raspberryconnect.com zu Verfügung gestellt.

Die Inbetriebnahme ist sehr intuitiv:

- Dateien mit folgendem Kommando herunterladen:

curl "https://www.raspberryconnect.com/images/hsinstaller/AutoHotspotSetup.tar.gz" -o AutoHotspot-Setup.tar.gz

- Dateien auspacken:

tar -xzvf AutoHotspot-Setup.tar.gz

- Entpackte Ordner öffnen:
- cd Autohotspot
- Installationsskript mit Administrationsrechte ausführen:
- sudo ./autohotspot-setup.sh
- Ein Menü mit acht Einträgen wird angezeigt. «1» muss eingegeben werden, um den ersten Eintrag auszuwählen. Die Software wird nun installiert.
- Nachdem die Installation abgeschlossen wurde, muss das System neu gestartet werden.

### Netzwerktopologie

#### 3.3.1.1 Access Point

Falls keine bekannten Wlan-Netzwerke verfügbar sind, sieht die Netzwerktopologie wie folgt aus. Die Ethernet Verbindung ist fakultativ. Die DHCP wird vom Raspberry verwaltet.

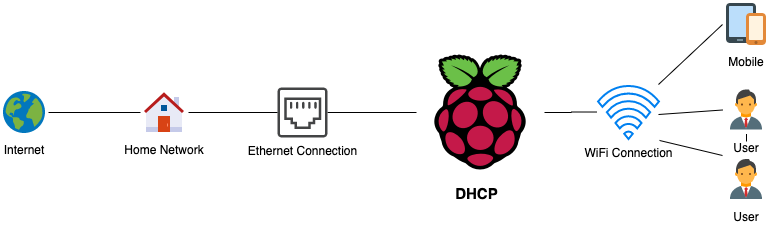
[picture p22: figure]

Abbildung 14: Netzwerktopologie Access Point

#### 3.3.1.2 Eigene WiFi Netzwerk

Falls eine Verbindung zu einem bekannten Wlan-Netzwerk hergestellt werden kann, sieht die Netzwerktopologie wie folgt aus. Die DHCP wird vom Besitzer der WiFi AP verwaltet.

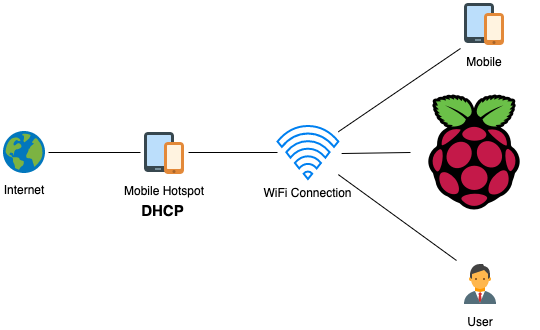
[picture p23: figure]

Abbildung 15: Netzwerktopologie eigene WiFi Network

# 4 Schlussbetrachtung

## 4.1 Fazit

Das berrycase Gehäuse erfüllt alle grundlegenden Ziele, welche im Pflichtenheft angegeben wurden. Es konnte auch angefangen werden, am optionalen Ziel zu Arbeiten. Dieses wurde aber nicht abgeschlossen. Das Gerät kann mit dem OLED Display und dem Navigationstaster angesteuert werden. Mit einem Akku kann der Raspberry auch unterwegs benutzt werden.

Alles in allem würde ich die Arbeit als gelungen betrachten. Ich konnte das Wissen, welches ich aus der Vorarbeit erarbeitet habe, gut anwenden und habe auch noch einiges an neuem Wissen dazugewonnen. Vor allem im Bereich Networking konnte ich noch einiges dazulernen. Obwohl ich nicht ein 3D Gehäuse zeichnen und erstellen konnte, war die Arbeit mit viel Spass verbunden und sehr abwechslungsreich.

## 4.2 Verbesserungsmöglichkeiten

Trotz sauberem Vorgehen während der Arbeit konnten noch einige kleine Fehler entdeckt werden, welche bei späteren Versionen korrigiert werden sollten.

### Hardware

- Der Footprint des PowerBoost Bauteils muss korrigiert werden. Pin 6 und Pin 7 wurden verstauscht gezeichnet.
- Die Flip-Flop Schaltung kann verbessert werden. Der MOSFET Schaltung für das Set Pin das Flip-Flop kann mit ein Schottky Diode ersetzt werden.

### Software

- Die Steuerung der Lüfter kann verbessert werden. Das PWM Signal ist nicht sehr sauber und präzis. Grund dafür ist, dass das Signal softwaremässig mit einer höheren Programmiersprache (Python) erzeugt wird. Die Steuerung der Lüfter könnte im C geschrieben werden.
- Die Entladekurve des eingesetztes Akkus kann in Form von einer Lookup Table im Hauptprogramm hinzugefügt werden. So kann der Ladezustand besser abgebildet werden.

## 4.3 Ausblicke

Ein kritischer Punkt, um die Beständigkeit des Geräts zu gewährleisten wäre die Herstellung eins geeigneten Gehäuses. Das Gehäuse wird sicherlich nach Projektabschluss noch entwickelt. Das Gerät wird auch weiterentwickelt und verbessert. Es ist nicht auszuschliessen, dass bei genügender Nachfrage das Gerät auch kommerzialisiert werden könnte.

# 5 Glossar

Wort | Beschreibung
Einplatinencomputer | Ein Einplatinencomputer ist ein Computersystem, bei dem sämtliche zum Betrieb nötigen elektronischen Komponenten auf einer einzigen Leiterplatte zusammengefasst sind.
Github | GitHub ist ein netzbasierter Dienst zur Versionsverwaltung für Software-Entwicklungsprojekte.
Entprellung | Durch die prellenden Schließvorgänge würde ohne Entprellung ein Tastenanschlag fehlerhafterweise als mehrfacher Anschlag registriert werden.
Freilaufdiode | Freilaufdioden sind Bauteile, welche zum Schutz vor Überspannung oder unerlaubten Spannungen eingesetzt werden.
Pull-up | Elektrische Trennung zweier Stromkreise.
Bash | Bash, die Bourne-again shell, ist eine freie Unix-Shell unter GPL.
Cron | Der Cron-Daemon dient der zeitbasierten Ausführung von Prozessen in Unix und unixartigen Betriebssystemen wie Linux, BSD oder macOS, um wiederkehrende Aufgaben – Cronjobs – zu automatisieren.
Access Point | Ein Wireless Access (englisch für drahtloser Zugangspunkt), auch Access Point (AP) oder Basisstation genannt, ist ein elektronisches Gerät, das als Schnittstelle für kabellose Kommunikationsgeräte fungiert.
Netzwerktopologie | Die Topologie eines Rechnernetzes beschreibt die spezifische Anordnung der Geräte und Leitungen, die ein Rechnernetz bilden, über das die Computer untereinander verbunden sind und Daten austauschen.
Footprint | Ein Footprint ist die Anordnung von Pads (in der Oberflächenmontagetechnik) oder Durchgangslöchern (in der Durchstecktechnik), die zur physischen Befestigung und elektrischen Verbindung eines Bauteils mit einer Leiterplatte verwendet wird.
Lookup Table | Lookup-Tabellen bzw. Umsetzungstabellen werden in der Informatik und in der Digitaltechnik verwendet, um Informationen statisch zu definieren und diese zur Laufzeit des Programms – zur Vermeidung aufwändiger Berechnungen oder hohen Speicherverbrauchs – zu benutzen.

# 6 Literatur- und Quellenverzeichnis

Auf den folgenden Seiten werden alle verwendeten Quellen angegeben.

PowerBoost 1000C
Autor: lady ada
Link: https://www.adafruit.com/product/2465 (Stand:13.12.2020)

OLED Display
Autor: Unbekannt
Link: https://github.com/adafruit/Adafruit_CircuitPython_SSD1306 (Stand: 13.12.2020)

Raspberry Pi 4 Schematics
Autor: James Adams
Link: https://www.raspberrypi.org/documentation/hardware/raspberrypi/schematics/rpi_SCH_4b_4p0_reduced.pdf (Stand: 13.12.2020)

Introduction to USB Type-C™
Autor: Andrew Rogers
Link: http://ww1.microchip.com/downloads/en/appnotes/00001953a.pdf (Stand: 13.12.2020)

Command to display Memory usage, Disk Usage and CPU Load
Autor: terdon
Link: https://unix.stackexchange.com/questions/119126/command-to-display-memory-usage-disk-usage-and-cpu-load (Stand: 13.12.2020)

Raspberry Pi Automatic Hotspot and Static Hotspot Installer
Autor: Unbekannt
Link: https://www.raspberryconnect.com/projects/65-raspberrypi-hotspot-accesspoints/183-raspberry-pi-automatic-hotspot-and-static-hotspot-installer (Stand:03.04.2018)

# 7 Anhang

## 7.1 Zeitplan

## 7.2 Aufgabestellung

Cirignaco EnricoCirignaco Enrico 2 Yannick Burkhalter IPA Elektroniker 05.02.21

2 Enrico Cirignaco BüP Elektroniker 05.02.21

7 Enrico Cirignaco BüP Elektroniker 05.02.21

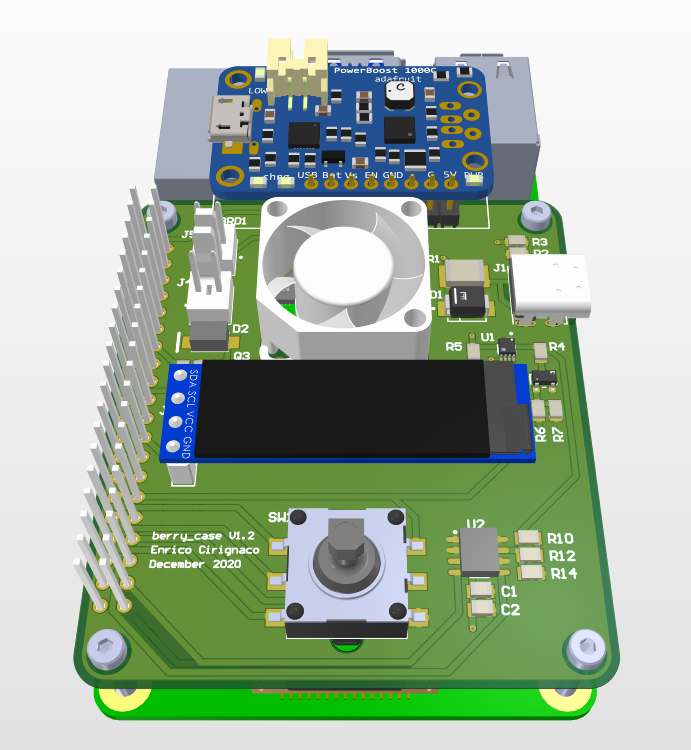
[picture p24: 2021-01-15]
ressources/images/v1.2_side.png

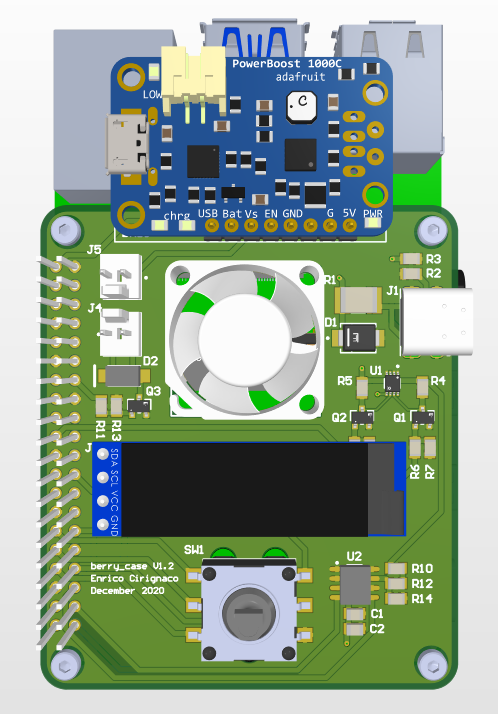
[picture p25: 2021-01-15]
ressources/images/v1.2_top.png

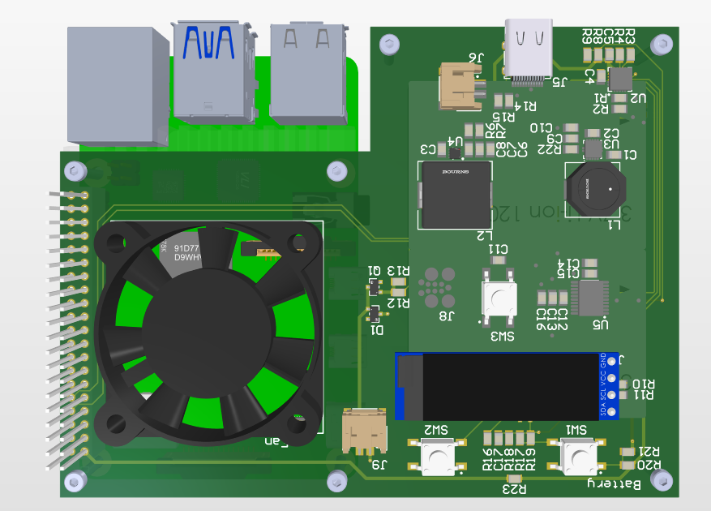
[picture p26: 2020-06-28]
ressources/images/v0.1_top.png

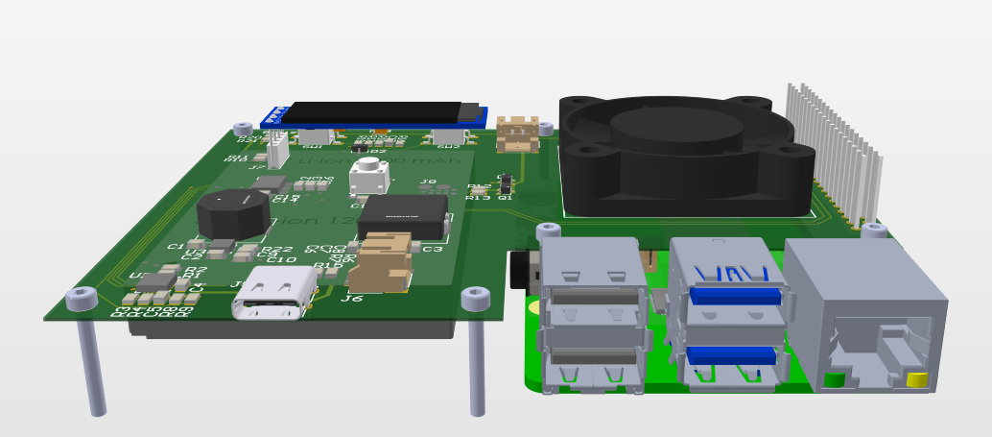
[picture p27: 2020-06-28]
ressources/images/v0.1_side.png

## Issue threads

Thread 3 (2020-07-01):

PCB Bottom side

enricocirignaco, 2020-07-01:
The only purpose of this PCB is to take HDMI and Audio ports to the back. I had some difficulty to find a micro HDMI male SMD plug. So a solution should be found.
What is better?
- Stick with the PCB solution
- micro HDMI plug to ribbon cable
- other solution(?)

Schematic and PCB files are already available in the Altium Project

NoFu1, 2020-07-01:
[here](https://www.digikey.com/product-detail/en/molex/0467650001/WM1281DKR-ND/2330704)'s a SMD micro HDMI connector

Closed 2020-11-24.

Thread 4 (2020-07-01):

3D printable case

enricocirignaco, 2020-07-01:
Suggestions and Prototypes are welcome.
I had something like the Argon One case in mind. I personally think is a good design.
One requirement is that it must be 3D printable so that everyone can print its own at home.

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

enricocirignaco, 2020-07-01:
A 3D model of the Top PCB was already exported from Altium. Could help while designing the case.
[3D model Top Board](https://github.com/enricocirignaco/berry_case/blob/master/ressources/pcb_top.step)

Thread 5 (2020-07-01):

Find Solution to solder Regulators

enricocirignaco, 2020-07-01:
No stencil will be sent with the PCB. The two regulators can only be soldered with hot air method. (see footpints)
Solution is needed.

enricocirignaco, 2020-07-01:
Maybe stencils from other designs with the same footprint can be used

NoFu1, 2020-07-01:
I think another footprint would be better, it would be easier to DIY if you dont need an Hot Air station.

enricocirignaco, 2020-07-01:
That is actually a good point!
I already ordered the V0.1 PCB so I can't modify it anymore.
But it's a good input for next version :)

NoFu1, 2020-07-03:
ive done it some times, for a single piece its no problem to put a little bit of solder on the pads(with the Iron) and the heat it with hot air till it melts, put the component on it -> DONE!

Closed 2020-11-24.

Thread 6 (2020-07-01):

Get all needed components

enricocirignaco, 2020-07-01:
Check which components are already available and which should be ordered.
Order needed components

enricocirignaco, 2020-07-01:
When I get back to work I will check what is available there.
@NoFu1 could you also check it?
Here is the [BOM](https://github.com/enricocirignaco/berry_case/blob/master/docs/pcb_assembly.PDF)

NoFu1, 2020-07-01:
@enricocirignaco we don't have any components at work, apart from some R/C etc

Closed 2020-11-24.

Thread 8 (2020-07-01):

PCB Project

NoFu1, 2020-07-01:
1. Create (usable) Folder structure
2. Cleanup all schematics
3. Create separate Projects for bottom/upper PCB
4. add TOP OVERLAY on C/Rs
5. Change charge controller and step - down converter to DIP
6. removing all angles < 90°
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
8. make use of polygons
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

enricocirignaco, 2020-07-01:
About point 3...what do you think about [multi board project](https://www.altium.com/documentation/altium-designer/designing-systems-with-multiple-boards-ad?version=18.1)?
I have no experience with that but maybe it's useful.

enricocirignaco, 2020-07-01:
About point 5...I already checked it. The TPS63031 is only available in VSON package. and the TPS61022 only in VQFN package.

NoFu1, 2020-07-01:
I think multboard designs are a pain to use. I will use some other types(with a more practical footprint), shouldn't be a problem

NoFu1, 2020-07-03:
@enricocirignaco tell me, when you have the PCB and know what should be changed, if u dont mind i will do the design. So you could start with the Firmware

enricocirignaco, 2020-07-04:
Okay, we could create a issue for every bug or improovment that need to be changed. I will create a tag so you can find all the issues fast.

enricocirignaco, 2020-07-06:
The PCB arrived. But I don't have the components yet. I will update you

Closed 2020-11-24.

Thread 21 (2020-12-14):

Fix Footprint PowerBoost 1000C

enricocirignaco, 2020-12-14:
Pin 2 & 3 are wrong --> Pin 2 is Vlipo and Pin3 is Vbat

Closed 2021-01-29.

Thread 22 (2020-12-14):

Fix Flip-Flop Circuit

enricocirignaco, 2020-12-14:
MOSFET Circuit for Set Pin of Flip-Flop must be replaced by a single Schottky diode.

Closed 2021-01-29.

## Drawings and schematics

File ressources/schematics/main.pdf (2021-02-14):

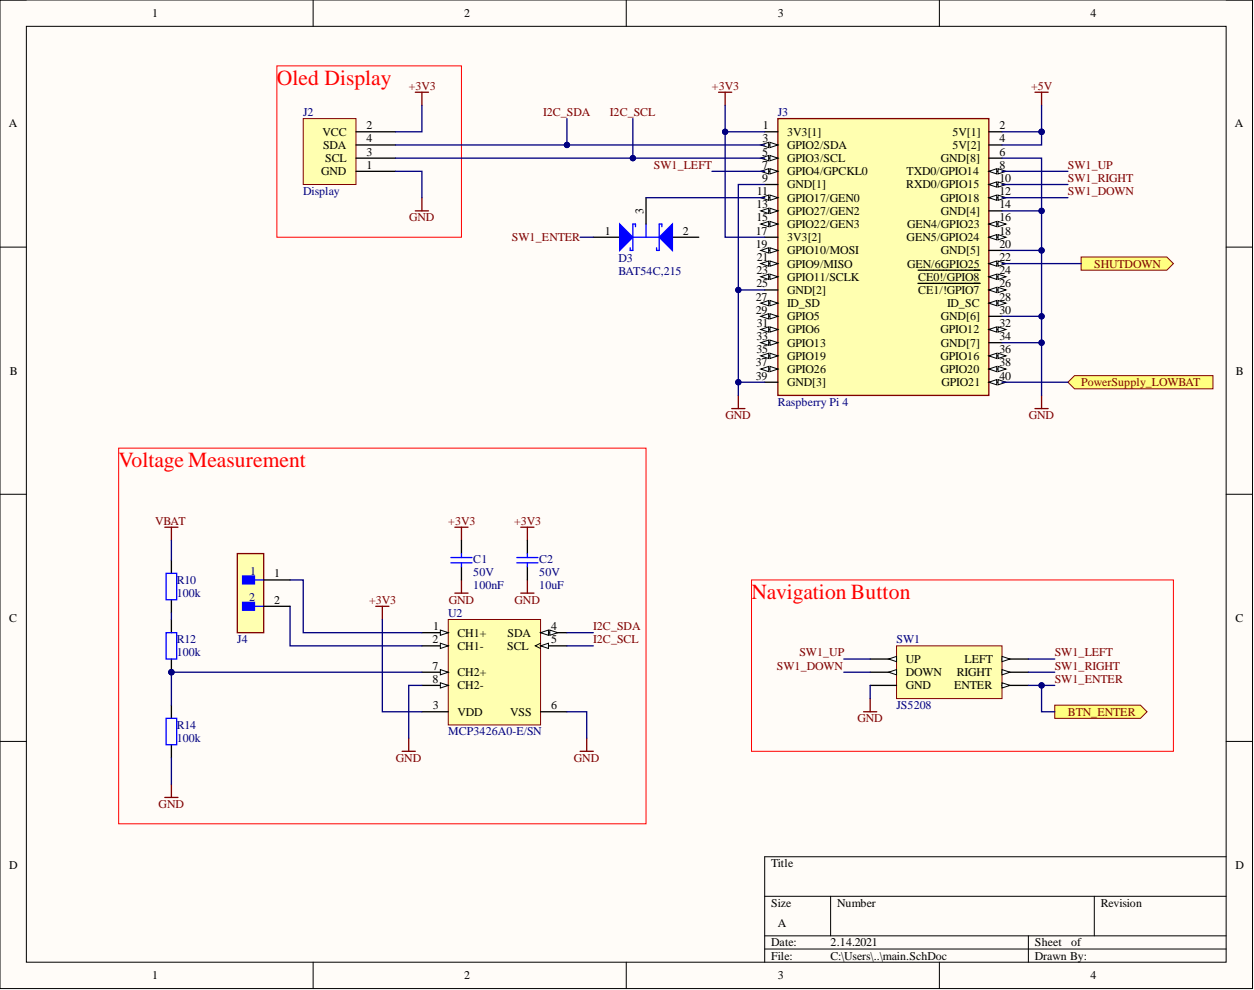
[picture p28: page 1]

GPIO3/SCL 5

GPIO17/GEN0 11

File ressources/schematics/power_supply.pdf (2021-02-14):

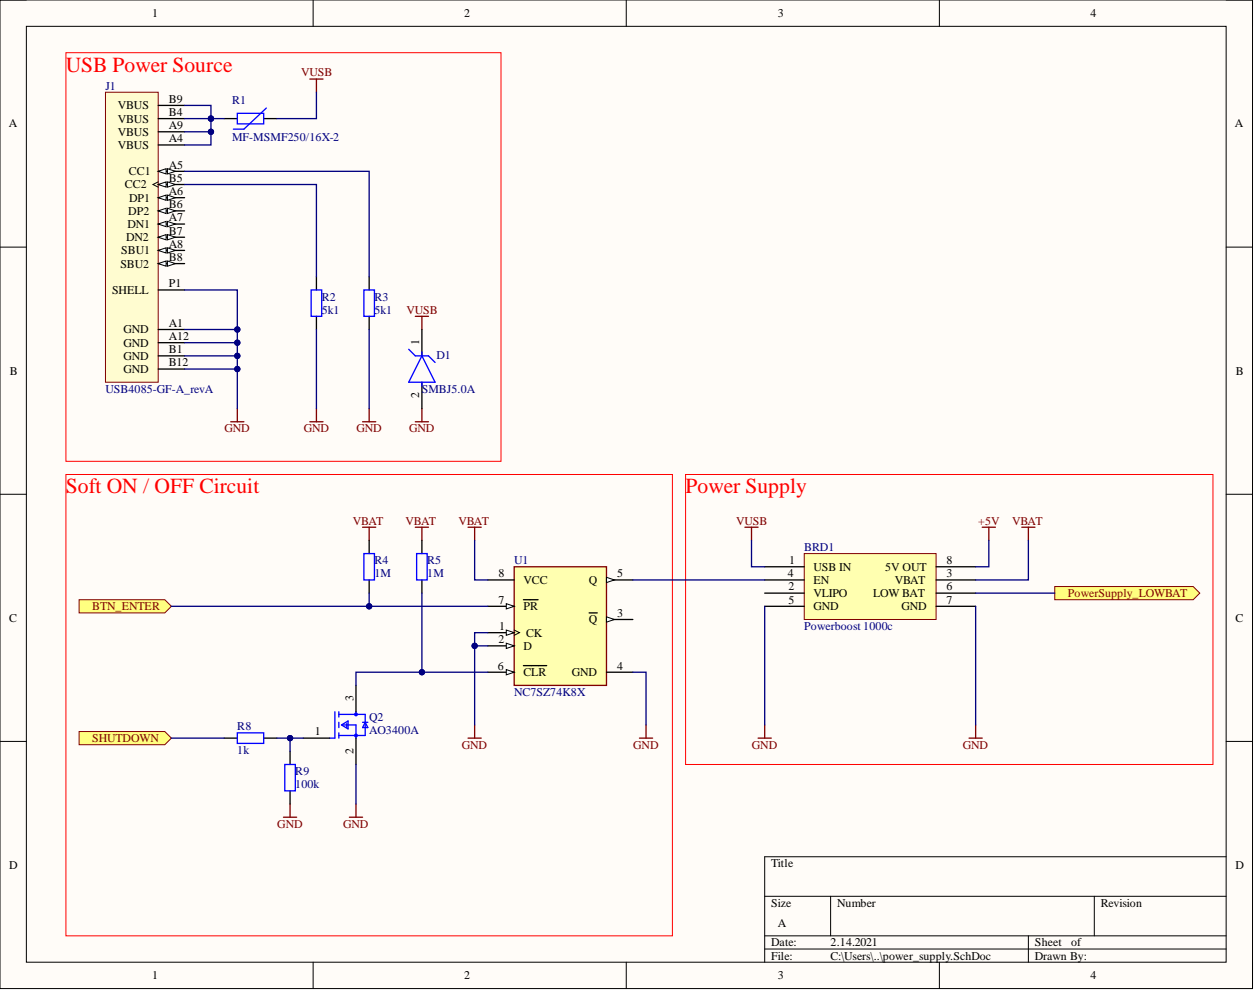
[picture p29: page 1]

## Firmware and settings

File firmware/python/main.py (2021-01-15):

# Project:   berry_case
# File:      main program
# Autor:     Enrico Cirignaco
# Created:   22.11.2020

# Import modules
#############################################################################
import time
import oled_display
import gpio
import parameters
import globals
import handlers


# Setup
#############################################################################
gpio.init()
oled_display.init()
parameters.update_dynamic_parameters()

oled_display.draw_entry("Berrycase v0.2", 16)
time.sleep(2)
oled_display.draw_entry(parameters.DEPTH_0_LABELS[0], parameters.MAIN_ENTRY_FONT_SIZE)

# Endless Loop
#############################################################################
try:
    while True:
        # update system and network values every second if in that submenu
        if globals.menu_depth == 1 and (globals.main_menu_entry == 0 or globals.main_menu_entry == 1):
            parameters.update_dynamic_parameters()
            handlers.update_submenu()
        
        # turn off dsplay after x seconds of inactivity
        if globals.display_counter == parameters.DISPLAY_TIMEOUT:
            oled_display.draw_turn_off()
        elif globals.display_counter < parameters.DISPLAY_TIMEOUT:
            globals.display_counter += 1
            
        time.sleep(1)
except KeyboardInterrupt:
    oled_display.draw_turn_off()
    gpio.GPIO.cleanup()

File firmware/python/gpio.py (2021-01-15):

# Project:   berry_case
# File:      gpio module
# Autor:     Enrico Cirignaco
# Created:   27.11.2020

# Import modules
#############################################################################
import time
import RPi.GPIO as GPIO
import parameters
import globals
import handlers
import subprocess

# Init navigation button
#############################################################################
def init():
    # Use BCM pin numbering
    GPIO.setmode(GPIO.BCM)
    # Setup GPIOs as input with pullup resistor
    GPIO.setup(parameters.BTN_LEFT_GPIO, GPIO.IN, pull_up_down=GPIO.PUD_UP)
    GPIO.setup(parameters.BTN_RIGHT_GPIO, GPIO.IN, pull_up_down=GPIO.PUD_UP)
    GPIO.setup(parameters.BTN_UP_GPIO, GPIO.IN, pull_up_down=GPIO.PUD_UP)
    GPIO.setup(parameters.BTN_DOWN_GPIO, GPIO.IN, pull_up_down=GPIO.PUD_UP)
    GPIO.setup(parameters.BTN_CENTER_GPIO, GPIO.IN, pull_up_down=GPIO.PUD_UP)
    # Create callback event for every GPIOs on falling edge. Debounce buttons.
    GPIO.add_event_detect(  parameters.BTN_LEFT_GPIO,
                            GPIO.FALLING,
                            callback=handlers.btn_left_callback,
                            bouncetime=parameters.BOUNCETIME_MS)
    
    GPIO.add_event_detect(  parameters.BTN_RIGHT_GPIO,
                            GPIO.FALLING,
                            callback=handlers.btn_right_callback,
                            bouncetime=parameters.BOUNCETIME_MS)

    GPIO.add_event_detect(  parameters.BTN_UP_GPIO,
                            GPIO.FALLING,
                            callback=handlers.btn_up_callback,
                            bouncetime=parameters.BOUNCETIME_MS)

    GPIO.add_event_detect(  parameters.BTN_DOWN_GPIO,
                            GPIO.FALLING,
                            callback=handlers.btn_down_callback,
                            bouncetime=parameters.BOUNCETIME_MS)

    GPIO.add_event_detect(  parameters.BTN_CENTER_GPIO,
                            GPIO.FALLING,
                            callback=handlers.btn_center_callback,
                            bouncetime=parameters.BOUNCETIME_MS)

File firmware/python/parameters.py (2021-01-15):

# Project:   berry_case
# File:      parameters.py
# Autor:     Enrico Cirignaco
# Created:   29.11.2020

# Import modules
#############################################################################
import subprocess
import adc

# Define Parameters
#############################################################################
# Menu specific
BASH_COMMANDS = {
    "SSID": "iwgetid -r",
    "IP": "hostname -I | cut -d' ' -f1 | tr -d '\n'",
    "HOSTNAME": "hostname | tr -d '\n'",
    "CPU": "top -bn1 | grep load | awk '{printf \"%.2f%%\", $(NF-2)}'",
    "CPU_TEMP": "cat /sys/class/thermal/thermal_zone0/temp | awk '{printf \"%.2f\", $1/1000}'",
    "MEMORY": "free -m | awk 'NR==2{printf \"%.2f%%\", $3*100/$2 }'",
    "DISK": 'df -h | awk \'$NF=="/"{printf "%d/%dGB  %s", $3,$2,$5}\''
}
DEPTH_0_LABELS = [
    "Network",
    "System Info",
    "Reboot",
    "Power OFF",
    "Fan Settings"
]
DEPTH_1_NETWORK_LABELS =["","",""]
DEPTH_1_SYSTEM_INFO_LABELS = ["","","","",""]
MAIN_MENU_ENTRY_CNT = len(DEPTH_0_LABELS)
NETWORK_MENU_ENTRY_CNT = len(DEPTH_1_NETWORK_LABELS)
SYSTEM_INFO_MENU_ENTRY_CNT = len(DEPTH_1_SYSTEM_INFO_LABELS)
MAIN_ENTRY_FONT_SIZE = 18
NETWORK_ENTRY_FONT_SIZE = 12
SYSTEM_INFO_ENTRY_FONT_SIZE = 12
SHUTDOWN_FONT_SIZE = 14

# Gpio specific
BTN_RIGHT_GPIO = 4
BTN_LEFT_GPIO = 15
BTN_UP_GPIO = 18
BTN_DOWN_GPIO = 14
BTN_CENTER_GPIO = 17
BOUNCETIME_MS = 200

# Display specific
TOP_PADDING = 6
RIGHT_PADDING = 6
DISPLAY_WIDTH = 128
DISPLAY_HEIGHT = 32
FONT_PATH = '/usr/share/fonts/truetype/dejavu/DejaVuSans.ttf'
DISPLAY_TIMEOUT = 20

# Function to update dynamic parameters
#############################################################################
def update_dynamic_parameters():
    global DEPTH_1_NETWORK_LABELS
    global DEPTH_1_SYSTEM_INFO_LABELS
    
    try:
        DEPTH_1_NETWORK_LABELS[0] = "SSID:" + subprocess.check_output(BASH_COMMANDS["SSID"], shell=True).decode("utf-8")
    except subprocess.CalledProcessError:
        DEPTH_1_NETWORK_LABELS[0] = "SSID:berrycase "
    try:
        DEPTH_1_NETWORK_LABELS[1] = subprocess.check_output(BASH_COMMANDS["IP"], shell=True).decode("utf-8")
    except subprocess.CalledProcessError:
        DEPTH_1_NETWORK_LABELS[1] = "No IP"
    try:
        DEPTH_1_NETWORK_LABELS[2] = "Host:" + subprocess.check_output(BASH_COMMANDS["HOSTNAME"], shell=True).decode("utf-8") + " "
    except subprocess.CalledProcessError:
        DEPTH_1_NETWORK_LABELS[2] = "No Hostname"
    
    DEPTH_1_SYSTEM_INFO_LABELS = [
        "Battery: " + str(adc.get_voltage_mv()) + "mV",
        "CPU Load: " + subprocess.check_output(BASH_COMMANDS["CPU"], shell=True).decode("utf-8"),
        "Memory: " + subprocess.check_output(BASH_COMMANDS["MEMORY"], shell=True).decode("utf-8"),
        "Disk: " + subprocess.check_output(BASH_COMMANDS["DISK"], shell=True).decode("utf-8"),
        "CPU Temp: " + subprocess.check_output(BASH_COMMANDS["CPU_TEMP"], shell=True).decode("utf-8")+ "°C",
    ]

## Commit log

2020-06-11 Altium project created
    [berry_case_altium.PrjPcb, pcb.PcbDoc, schematic.SchDoc]
2020-06-11 Schematic and PCB library created. Altium project saved.
    [PcbLib.PcbLib, Schlib.SchLib, berry_case_altium.PrjPcb]
2020-06-11 USB C, HDMI and AUIO jack added to library.
    [PcbLib.PcbLib, Schlib.SchLib, pcb.PcbDoc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]
2020-06-11 USB port, HDMI, and audio jack added to schematics
    [schematic.SchDoc]
2020-06-11 Board Shape Definited.
    [pcb.PcbDoc]
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2020-06-11 Schema and Pcb files for PowerBoost 1000c added to project.
    [Adafruit PowerBoost 1000C Rev B.PcbDoc, Adafruit PowerBoost 1000C Rev B.SchDoc]
2020-06-13 Add USB C Male footprint to schematics and PCB.
    [Schlib.SchLib, berry_case_altium.PrjPcb, pcb.PcbDoc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]
2020-06-21 Add stackable Header 40P to library. New PCB file board created. Header centered with PCB and Raspberry.
    [Schlib.SchLib, berry_case_altium.PrjPcb, pcb.PcbDoc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]
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2020-06-21 Oled Display, Push Button and Heatsink objects added to library. Oled Display, PowerBoost Circuit, USB C Port, Push buttons and Heatsink Added to Top PCB.
    [Schlib.SchLib, schematic.SchDoc]
2020-06-21 Critical components TPS63031, TPS61022, STM32F030 and MCP73871T-2CCI added to library
    [Adafruit PowerBoost 1000C Rev B.PcbDoc, Schlib.SchLib, berry_case_altium.PrjPcb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]
2020-06-22 Battery charger circuit implemented
    [power_supply.SchDoc]
2020-06-22 5V Booster circuit implemented
    [power_supply.SchDoc]
2020-06-22 3.3v Buck Boost Circuit implemented
    [power_supply.SchDoc]
2020-06-22 Power Supply ready to be routed
    [Schlib.SchLib, berry_case_altium.PrjPcb, power_supply.SchDoc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]
2020-06-22 Power Supply Parts generated in pcb_top
    [power_supply.SchDoc]
2020-06-22 New schematics sheet added. Main and MCU sheet.
    [MCU.SchDoc, berry_case_altium.PrjPcb, main.SchDoc]
2020-06-22 MCU schematic sheet completed
    [MCU.SchDoc, Schlib.SchLib, berry_case_altium.PrjPcb]
2020-06-25 SWD Interface added
    [MCU.SchDoc]
2020-06-25 footprint SMD changed from 1206 to 0805. J link connector added. PCB Top ready to be routed
    [MCU.SchDoc, Schlib.SchLib, berry_case_altium.PrjPcb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]
2020-06-26 PCB Top routed. Bugfix: Pullups I2C
    [MCU.SchDoc, Schlib.SchLib, berry_case_altium.PrjPcb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]
2020-06-26 Add Mounting Holes. Add PWM circuit for fan driving
    [MCU.SchDoc, Schlib.SchLib, power_supply.SchDoc]
2020-06-26 Add Raspberry sheet to project
    [Schlib.SchLib, berry_case_altium.PrjPcb, main.SchDoc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]
2020-06-26 Raspberry Connected via USART
    [Schlib.SchLib, berry_case_altium.PrjPcb, raspberry_interface.SchDoc]
2020-06-27 Add USB C Resistors. Power connected to RPi4
    [Schlib.SchLib, power_supply.SchDoc, raspberry_interface.SchDoc]
2020-06-27 Add variant 2 of Power Supply
    [MCU.SchDoc, Schlib.SchLib, berry_case_altium.PrjPcb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]
2020-06-27 Version 2 of power supply successfully routed.
    [MCU.SchDoc, berry_case_altium.PrjPcb, main.SchDoc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]
2020-06-27 Minor Improovement
    [Schlib.SchLib]
2020-06-28 Add 3.5mm stereo jack male
    [Schlib.SchLib, berry_case_altium.PrjPcb, schematic.SchDoc]
2020-06-28 Power Bosst 1000C files deleted.
    [Adafruit PowerBoost 1000C Rev B.PcbDoc, Adafruit PowerBoost 1000C Rev B.SchDoc]
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2020-06-29 Minor changes, bugfixes
    [berry_case_altium.PrjPcb]
2020-06-29 pcb file folder renamed.
    [MCU.SchDoc, Schlib.SchLib, berry_case_altium.PrjPcb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]
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2020-09-23 add IPA template documents to repo.
    [Linearisierung 4-20 mA Schnittstelle.xlsx, Stückliste.xlsx, Testprotokoll_SW.xlsx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]
2020-10-09 PCB V0.2 --> MCU changed, Footprint Display modified, uart pins switched.
    [MCU.SchDoc, Schlib.SchLib, berry_case_altium.PrjPcb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]
2020-10-09 PCB Project ready for V0.2 production.
    [MCU.SchDoc, Schlib.SchLib, berry_case_altium.PrjPcb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]
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2020-11-24 Schematics heavily modified. New sheets structure, only a power supply and a main sheet. Schematics ready for a review and pull request.
    [main.SchDoc, power_supply.SchDoc, raspberry_interface.SchDoc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]
2020-11-24 PCB concept. 20mm fan and battery pack 3d models added
    [Schlib.SchLib, berry_case_altium.PrjPcb]
2020-11-24 deleted unused altium files
    [MCU.SchDoc, power_supply_v2.SchDoc, schematic.SchDoc]
2020-11-25 bugfix: gpio and sda pin set as the same
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2020-11-27 bugfixes. Now code run again
    [gpio.py, oled_display.py]
2020-11-27 New footprints created. Main components fixed on board.
2020-11-27 broken footprints replaced. component placed on board
    [Schlib.SchLib, main.SchDoc, power_supply.SchDoc]
2020-11-28 Revert "bugfixes"
    This reverts commit 8bde18b92a26a18bb1f66e630fb713b1028f2471.
    [gpio.py]
2020-11-28 Revert "bugfixes. Now code run again"
    This reverts commit 986431688d406adbcfca770e6cbb1ebbf7090a65.
    [gpio.py, oled_display.py]
2020-11-28 now code run without error with gpio init commented
    [oled_display.py]
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2020-11-29 reboot and shutdown implemented but not tested
    [handlers.py, parameters.py]
2020-11-30 Board routing done. Board ready for review and order.
    [berry_case_altium.PrjPcb, main.SchDoc, power_supply.SchDoc]
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2020-11-30 production and documentation files for pcb v1.2 exported
    [pcb.GBL, pcb.GBO, pcb.GBP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]
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2020-12-05 bugfix: if display is off first button press only turn on display.
    [handlers.py, main.py]
2020-12-07 production files moved to other location. diagrams moved into diagrams forlder. grobdiagramm created.
    [pcb.GBL, pcb.GBO, pcb.GBP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]
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2020-12-12 ADC module added to repo. Battery dummy replaced by battery voltage
    [adc.py, main.py, parameters.py]
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2020-12-15 Zeitplan added. Documentation exported.
    [Zeitplan.xlsx]
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2021-01-15 unused files deleted.
    [Linearisierung 4-20 mA Schnittstelle.xlsx, Stückliste.xlsx, Testprotokoll_SW.xlsx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]
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2021-01-28 unused symbols deleted
    [Schlib.SchLib]
2021-01-29 Bugfix Issue #22. Circuit with Q1-R6-R7 replaced with by diode D3
    [berry_case_altium.PrjPcb, main.SchDoc, power_supply.SchDoc]
2021-01-29 Bugfix issue #21. Footprint powerboost fixed. battery connector removed.
    [Schlib.SchLib, power_supply.SchDoc]
2021-01-29 circuit for fan control removed
    [main.SchDoc]
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2021-01-30 ADC Header added to schematics and pcb
    [Schlib.SchLib, berry_case_altium.PrjPcb, main.SchDoc]
2021-02-14 resistors value changed for voltage divider
    [main.SchDoc]
2021-02-14 minor changes. Production files ready for order.
    [berry_case_altium.PrjPcb]
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
